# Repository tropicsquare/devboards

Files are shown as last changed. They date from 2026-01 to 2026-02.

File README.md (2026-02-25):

# TROPIC01 devboards
Welcome, PCB designers! 

This repository collects all resources for development boards which we designed with our TROPIC01 secure element. All PCB designs are freely available under **[CERN-OHL-P-2.0](https://ohwr.org/cernohl) Open Hardware license**. We encourage you to re-use designs, modify, or build your own boards!

> [!TIP]
> **Looking for code examples, ready to get started?** Head over to [libtropic](https://github.com/tropicsquare/libtropic) and pick a tutorial that matches your interests. Whether you're new to secure elements or building production systems, you'll find step-by-step guides to get you up and running quickly.

| Product name | HW resources | Description | Image  |
|:---:|:---:|:---:|:---:|
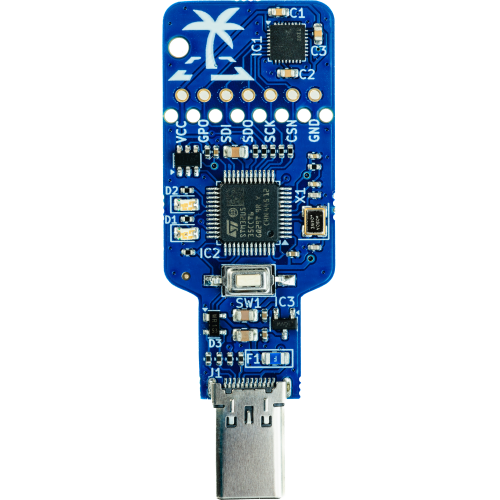
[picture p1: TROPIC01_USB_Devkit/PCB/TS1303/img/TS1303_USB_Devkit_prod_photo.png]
| **TROPIC01 USB Devkit** | [View](./TROPIC01_USB_Devkit/) | Suitable for TROPIC01 evaluation over USB. Besides the default functionality of SPI-UART translator which you can plug into PC and evaluate tropic on your laptop by using its serial port, this devkit is also capable of running USB application, because it contain also application MCU. This is ideal starting point for developing own USB application with TROPIC01. |  |
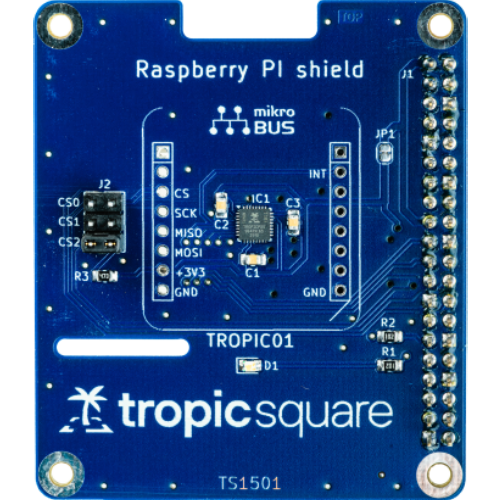
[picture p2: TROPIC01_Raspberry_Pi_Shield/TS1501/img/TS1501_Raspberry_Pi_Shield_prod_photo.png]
| **TROPIC01 Raspberry Pi Shield**  | [View](./TROPIC01_Raspberry_Pi_Shield/) | Chip is wired to SPI port pins commonly used on Raspberry Pi, ideally use this shield if you want to evaluate on `Raspberry Pi` or some other `Linux SBC` with the `Raspberry Pi` compatible header.  |  |
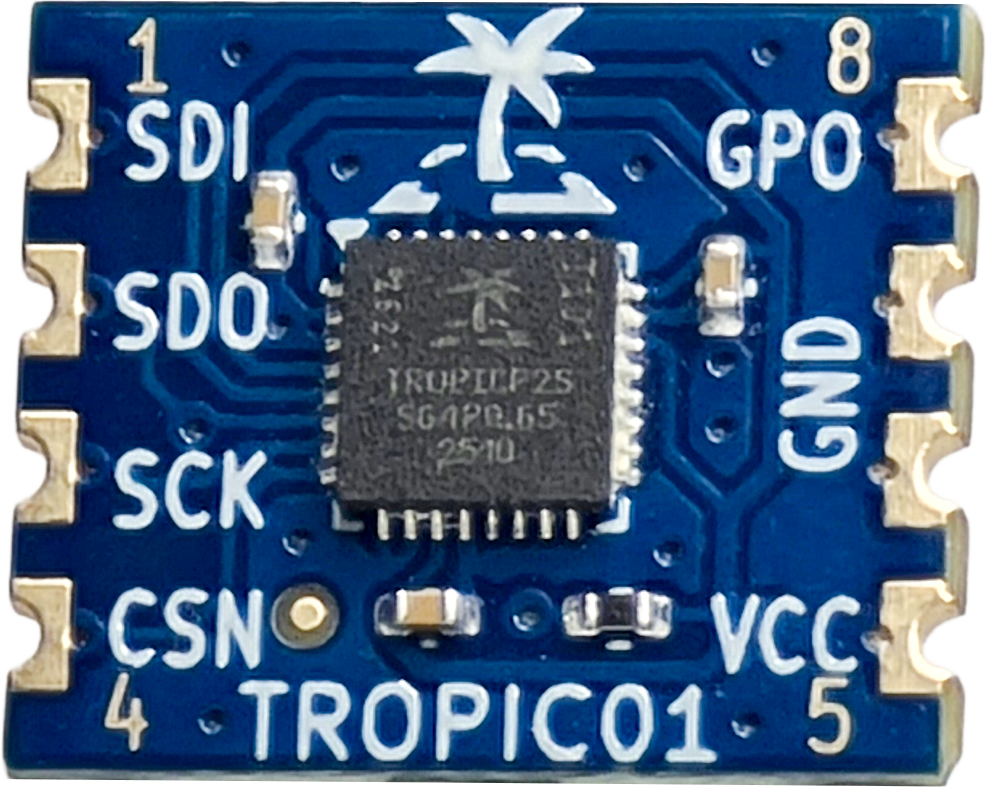
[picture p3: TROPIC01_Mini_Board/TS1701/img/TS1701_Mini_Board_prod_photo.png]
| **TROPIC01 Mini Board** | [View](./TROPIC01_Mini_Board/) | Minimalistic PCB breakout board for TROPIC01, designed to be soldered directly on host PCB, keeping the size small but still handy to hand solder. Suitable for placing on custom made shields or prototyping when PCB space is scarce. |  |
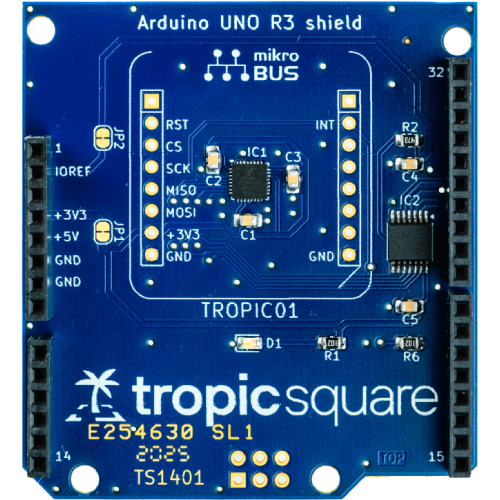
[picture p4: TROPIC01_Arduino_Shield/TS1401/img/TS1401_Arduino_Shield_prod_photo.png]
| **TROPIC01 Arduino Shield** | [View](./TROPIC01_Arduino_Shield/) | Chip is wired to SPI port pins commonly used on arduino compatible boards. Ideally use this shield if you want to evaluate on prototype which has `Arduino` header. |  |
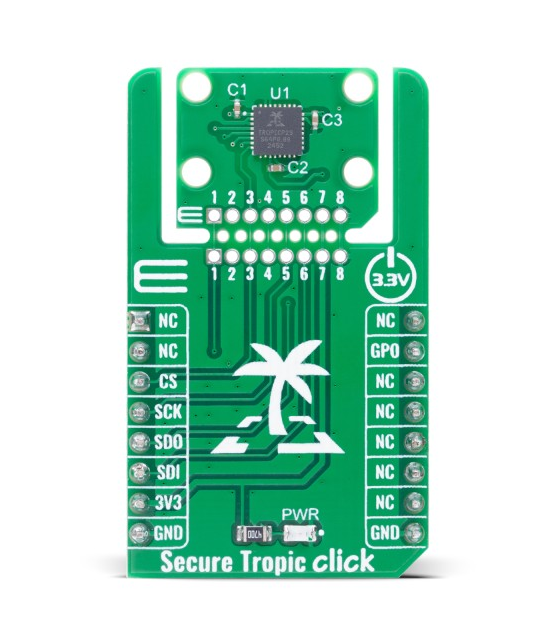
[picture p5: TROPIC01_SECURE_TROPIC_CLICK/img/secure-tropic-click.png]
| **TROPIC01 SECURE TROPIC CLICK**  | [View](./TROPIC01_SECURE_TROPIC_CLICK/) | Tthis is a third party devboard, with the similar functionality as other shields, but with another form factor. Fits into mikroBUS socket, or could be wired over wires as needed.|  |

## Using These Designs

Each particular board folder contains complete design files for all released revisions:
- **Schematics** (`.kicad_sch`) - Showing how components are wired together
- **PCB layouts** (`.kicad_pcb`) - Design of the PCB - how components are physically placed on the PCB
- **BOMs** - Component lists with part numbers
- **Gerbers** - Manufacturing files for PCB fabrication

You're free to use these as reference, modify for your needs, or manufacture your own boards.

> [!IMPORTANT]
> Some devboards include firmware in their folders. Note that firmware or its parts may be under various licensing schemes - see the [licensing section](#license) below for details.

## FAQ

See [FAQ.md](FAQ.md)

## Support & Warranty

These designs and devkits are provided as-is for evaluation and prototyping. No warranties are provided, and no production certifications (e.g., CE/FCC) are implied. Support is best-effort; for code examples and guidance, see [libtropic](https://github.com/tropicsquare/libtropic).

## License

This repository does not contain only PCB resources, but in some cases also HW which comes with devkit. Each part is under different license, more details in following table:

| Component | License  | Applies To |
|:---|:---|:---|
| **PCB Hardware** | [CERN-OHL-P-2.0](LICENSE.txt) | TROPIC01_Arduino_Shield/, TROPIC01_Raspberry_Pi_Shield/, TROPIC01_Mini_Board/, TROPIC01_USB_Devkit/PCB/ |
| **Firmware** | [BSD-3-Clause-Clear](LICENSES/FIRMWARE-LICENSE.txt) | TROPIC01_USB_Devkit/firmwares/ |
| **Third-party USB library** | Specific | TROPIC01_USB_Devkit/firmwares/firmware_B/sdk/ - See [LICENSES/NOTICE.txt](LICENSES/NOTICE.txt) |

## About TROPIC01

For more information about the TROPIC01 secure element, please see the official documentation:

*   [TROPIC01 Development resources](https://github.com/tropicsquare/tropic01/tree/main/)
*   [TROPIC01 Website](https://www.tropicsquare.com/tropic01)

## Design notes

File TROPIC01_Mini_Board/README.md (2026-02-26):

# TROPIC01 Mini Board

This repository contains **hardware** design files for the TROPIC01 Mini Board.

> [!TIP]
> **Looking for code examples, ready to get started?** Head over to [libtropic](https://github.com/tropicsquare/libtropic) and pick a tutorial that matches your interests. Whether you're new to secure elements or building production systems, you'll find step-by-step guides to get you up and running quickly.

## PCB Revisions + BOMs

Following folder contains schematics, layouts, BOMs and gerber files.

- **PCB [TS1701](./TS1701/)**

## Product Versions

| Product version | PCB Tracking | PCB Revision | TROPIC01 Part Number | BOM | Picture | Availability |
|:---:|:---:|:---:|:---:|:---:|:---:|:-----:|
| 2.0 | none | **TS1702** | TR01-C2P-T101 | [BOM](./TS1702/bom/ts17-tropic01-mini.csv) | [Top View](./TS1702/img/top.png) | [BUY HERE](https://www.tropicsquare.com/order-devkit)  |
| 1.0 | none | **TS1701** | TR01-C2P-T101 | [BOM](./TS1701/bom/ts17-tropic01-mini.csv) | [Top View](./TS1701/img/top.png) | [BUY HERE](https://www.tropicsquare.com/order-devkit)  |

## About TROPIC01

For more information about the TROPIC01 secure element, please see the official documentation:

*   [TROPIC01 Development resources](https://github.com/tropicsquare/tropic01/tree/main/)
*   [TROPIC01 Website](https://www.tropicsquare.com/tropic01)

## Support & Warranty

This board is provided as-is for evaluation and prototyping. No warranties are provided, and no production certifications (e.g., CE/FCC) are implied. Community-level support only; for examples and tutorials, visit [libtropic](https://github.com/tropicsquare/libtropic).

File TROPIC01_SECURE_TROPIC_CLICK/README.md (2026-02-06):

# TROPIC01 SECURE TROPIC CLICK

This repository contains references for TROPIC01 SECURE TROPIC CLICK. Please note that this Devboard is not developed by Tropic Square.

> [!TIP]
> **Looking for code examples, ready to get started?** Head over to [libtropic](https://github.com/tropicsquare/libtropic) and pick a tutorial that matches your interests. Whether you're new to secure elements or building production systems, you'll find step-by-step guides to get you up and running quickly.

## PCB Revisions + BOMs

None avaiable (Developed by MIKRO-E)

## Product Versions

| Product version | PCB Tracking | PCB Revision | TROPIC01 Part Number | BOM | Picture | Availability |
|:---:|:---:|:---:|:---:|:---:|:---:|:-----:|
| 1.1 | none | none | TR01-C2P-T101 | External vendor | [Top View](./img/secure-tropic-click.png) | [BUY HERE](https://www.tropicsquare.com/order-devkit)  |
| 1.0 | none | none | TR01-B2S-T005 | External vendor | [Top View](./img/secure-tropic-click.png) | [DEPRECATED]  |

## About TROPIC01

For more information about the TROPIC01 secure element, please see the official documentation:

*   [TROPIC01 Development resources](https://github.com/tropicsquare/tropic01/tree/main/)
*   [TROPIC01 Website](https://www.tropicsquare.com/tropic01)

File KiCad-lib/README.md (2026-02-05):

# TROPIC01 KiCad Library

This directory contains support files for designing PCB with TROPIC01, **Tested with KiCad 9.0**.

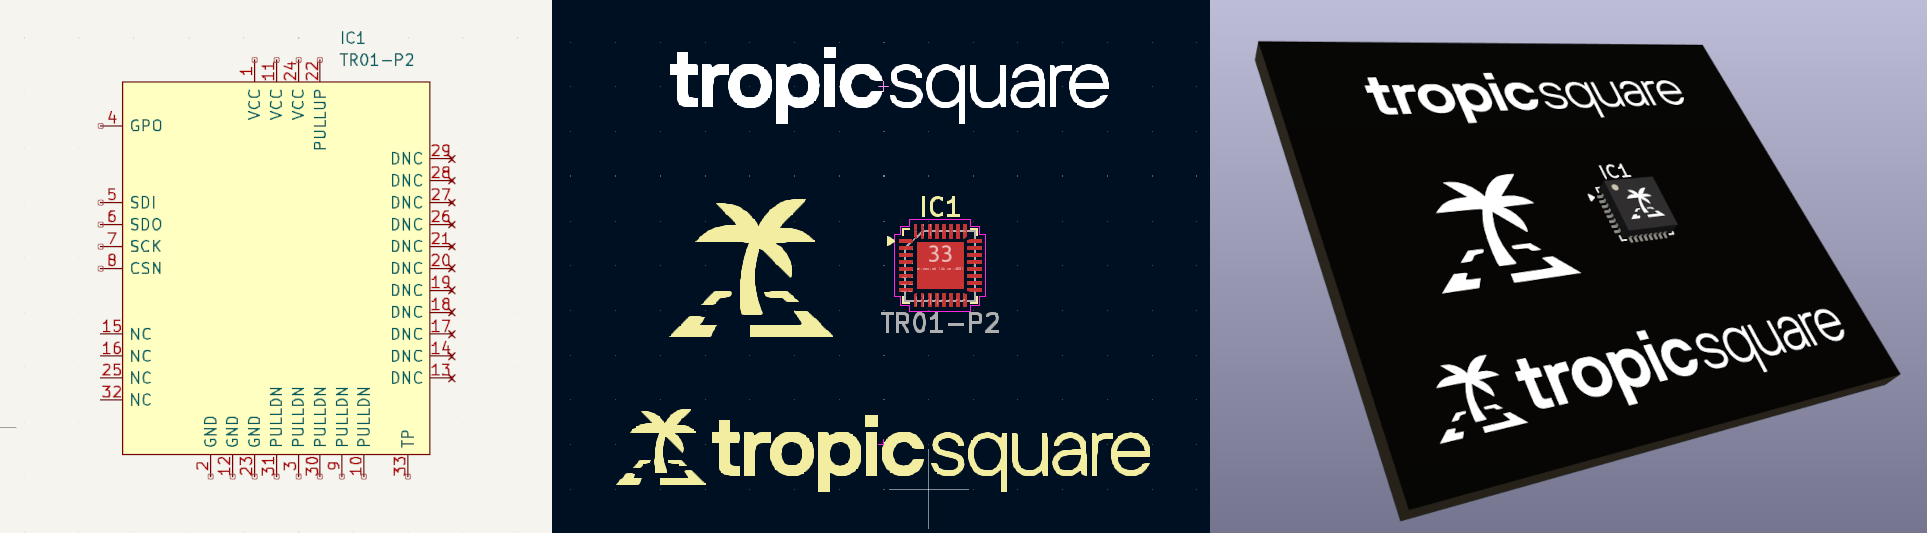
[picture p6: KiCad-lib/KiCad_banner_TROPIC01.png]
KiCad printscreens


## Content

- `TROPIC01.kicad_sym` - Symbol library containing schematic symbol for TROPIC01 chip
- `TROPIC01.step` - 3D STEP model for the TROPIC01 chip package
- `logos.pretty/` - Tropic Square logo and branding, provided as footprints, ready to be used in silkscreen

As footprint we recommend to use standard `Package_DFN_QFN:QFN-32-1EP_4x4mm_P0.4mm_EP2.65x2.65mm` provided by KiCad.

## Installation and Usage as Project-Specific Libraries (Recommended)

This method keeps the libraries just with your project. For more details refer to original KiCad documentation about how to use libraries.

1. **Copy the KiCad-lib folder** into your KiCad project directory or a subdirectory (e.g., `libraries/`)

2. **Add the Library:**
  - Open your KiCad project
  - Go to `Preferences` → `Manage Symbol Libraries...`
  - In the "Project Specific Libraries" tab, click the folder icon to add a new library
  - Browse to and select `TROPIC01.kicad_sym`
  - Give it a nickname (e.g., "TROPIC_SQUARE")
  - Click OK

3. **Add the Footprint Library:**
  - Go to `Preferences` → `Manage Footprint Libraries...`
  - In the "Project Specific Libraries" tab, click the folder icon to add a new library
  - Browse to and select the `logos.pretty` folder
  - Give it a nickname (e.g., "TROPIC_SQUARE"_Logos")
  - Click OK

4. **Configure 3D Model Path:**

By default, KiCad uses the standard 3D model for the QFN32 footprint. You can override this with our custom model to display the palm tree logo on the TROPIC01 package in the 3D viewer. To use our 3D model:
  - Open the PCB editor
  - Select a TROPIC01 footprint
  - Right-click → `Properties` → `3D Models` tab
  - Update the path so it points to provided `TROPIC01.step`

## Adding Logo Footprints to PCB

The logo footprints are designed for PCB silkscreen branding. They include various sizes to fit different board designs. These footprints contain only graphical elements and have no electrical connections.

1. Open the PCB Editor
2. Click the "Add Footprint" button (or press `O`)
3. In the footprint chooser, search for "tropicsquare"
4. Select the desired logo variant:
   - `tropicsquare_logo` - Full logo (default size)
   - `tropicsquare_logo_7` - Logo, 7mm
   - `tropicsquare_logo_8` - Logo, 8mm
   - `tropicsquare_name_7` - Company name text, 7mm
   - `tropicsquare_palm` - Palm icon (default size)
   - `tropicsquare_palm_8` - Palm icon, 8mm
   - `tropicsquare_palm_10` - Palm icon, 10mm
5. Place it on your PCB (typically on the silkscreen layer)

## License

See the LICENSE.txt file in the root directory for licensing information.

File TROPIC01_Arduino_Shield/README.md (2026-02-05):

# TROPIC01 Arduino Shield

This repository contains **hardware** design files for the TROPIC01 Arduino Shield.

> [!TIP]
> **Looking for code examples, ready to get started?** Head over to [libtropic](https://github.com/tropicsquare/libtropic) and pick a tutorial that matches your interests. Whether you're new to secure elements or building production systems, you'll find step-by-step guides to get you up and running quickly.

## PCB Revisions + BOMs

Following folder contains schematics, layouts, BOMs and gerber files.

- **PCB [TS1401](./TS1401/)**

## Product Versions

| Product version | PCB Tracking | PCB Revision | Product Variant | TROPIC01 Part Number  | BOM | Picture | Availability |
|:---:|:---:|:---:|:---:|:---:|:---:|:---:|:-----:|
| 1.2 | none | **TS1401** | Assembled with MikroBUS socket | TR01-C2P-T103 | [BOM](./TS1401/bom/bom_variant_microbus.csv) | [Top View](./TS1401/img/top.png) | [BUY HERE](https://www.tropicsquare.com/order-devkit) |
| 1.1 | E254630 SL1 |**TS1401**  | Assembled with chip | TR01-C2P-T101 | [BOM](./TS1401/bom/bom_variant_chip.csv) | [Top View](./TS1401/img/top.png) | [BUY HERE](https://www.tropicsquare.com/order-devkit) |
| 1.0 | E254630 SL1 | **TS1401** | Assembled with chip | TR01-B2S-T005 | [BOM](./TS1401/bom/bom_variant_chip.csv) | [Top View](./TS1401/img/top.png) | DEPRECATED  |

## About TROPIC01

For more information about the TROPIC01 secure element, please see the official documentation:

*   [TROPIC01 Development resources](https://github.com/tropicsquare/tropic01/tree/main/)
*   [TROPIC01 Website](https://www.tropicsquare.com/tropic01)

## Support & Warranty

This shield is provided as-is for evaluation and prototyping. No warranties are provided, and no production certifications (e.g., CE/FCC) are implied. Community-level support only; for examples and tutorials, visit [libtropic](https://github.com/tropicsquare/libtropic).

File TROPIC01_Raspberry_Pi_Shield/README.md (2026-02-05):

# TROPIC01 Raspberry Pi Shield

This repository contains **hardware** design files for the TROPIC01 Raspberry Pi Shield.

> [!TIP]
> **Looking for code examples, ready to get started?** Head over to [libtropic](https://github.com/tropicsquare/libtropic) and pick a tutorial that matches your interests. Whether you're new to secure elements or building production systems, you'll find step-by-step guides to get you up and running quickly.

## PCB Revisions + BOMs

Following folder contains schematics, layouts, BOMs and gerber files.

- **PCB [TS1501](./TS1501/)**

## Product Versions

| Product version | PCB Tracking | PCB Revision | TROPIC01 Part Number | BOM | Picture | Availability |
|:---:|:---:|:---:|:---:|:---:|:---:|:-----:|
| 1.2 | none | **TS1501** | TR01-C2P-T103  | [BOM](./TS1501/bom/bom_variant_chip.csv) | [Top View](./TS1501/img/top.png) | [BUY HERE](https://www.tropicsquare.com/order-devkit)  |
| 1.1 | none | **TS1501** | TR01-C2P-T101  | [BOM](./TS1501/bom/bom_variant_chip.csv) | [Top View](./TS1501/img/top.png) | DEPRECATED  |
| 1.0 | none | **TS1501** | TR01-B2S-T005  | [BOM](./TS1501/bom/bom_variant_chip.csv) | [Top View](./TS1501/img/top.png) | DEPRECATED  |

## About TROPIC01

For more information about the TROPIC01 secure element, please see the official documentation:

*   [TROPIC01 Development resources](https://github.com/tropicsquare/tropic01/tree/main/)
*   [TROPIC01 Website](https://www.tropicsquare.com/tropic01)

## Support & Warranty

This shield is provided as-is for evaluation and prototyping. No warranties are provided, and no production certifications (e.g., CE/FCC) are implied. Community-level support only; for examples and tutorials, visit [libtropic](https://github.com/tropicsquare/libtropic).

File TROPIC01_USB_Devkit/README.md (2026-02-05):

# TROPIC01 USB Devkit

This repository contains **hardware** design files for the TROPIC01 USB Devkit.

> [!TIP]
> **Looking for code examples, ready to get started?** Head over to [libtropic](https://github.com/tropicsquare/libtropic) and pick a tutorial that matches your interests. Whether you're new to secure elements or building production systems, you'll find step-by-step guides to get you up and running quickly.

## PCB Revisions + BOMs

Following folders contain schematics, layouts, BOMs and gerber files.

- **PCB [TS1301](./PCB/TS1301/)**
- **PCB [TS1302](./PCB/TS1302/)**
- **PCB [TS1303](./PCB/TS1303/)**

## Product Versions

| Product version | PCB Tracking  | PCB Revision  | MCU | TROPIC01 Part Number | BOM | Firmware | Picture | Availability |
|:----:|:---:|:---:|:---:|:---:|:---:|:---:|:---:|:-----:|
| 3.1  | none | **TS1303** | STM32U5 (512kB) | TR01-C2P-T103 | [BOM](./PCB/TS1303/bom/bom.csv) | [FW B](./firmwares/firmware_B/) | [Top View](./PCB/TS1303/img/top.png)  | [BUY HERE](https://www.tropicsquare.com/order-devkit)  |
| 3.0  | none | **TS1303** | STM32U5 (512kB) | TR01-C2P-T202 | [BOM](./PCB/TS1303/bom/bom.csv) | [FW B](./firmwares/firmware_B/) | [Top View](./PCB/TS1303/img/top.png)  | DEPRECATED  |
| 2.0  | none | **TS1302** | STM32U5 (256kB) | TR01-C2P-T101 | [BOM](./PCB/TS1302/bom/bom.csv) | [FW B](./firmwares/firmware_B/) | [Top View](./PCB/TS1302/img/top.png)  | DEPRECATED  |
| 1.0  | none | **TS1301** | STM32F1 (256kB) | TR01-B2S-T005 | [BOM](./PCB/TS1301/bom/bom.csv) | [FW A](./firmwares/firmware_A/) | [Top View](./PCB/TS1301/img/top.png)  | DEPRECATED  |
## PCB Specifications

Common specifications for all revisions:
- **Layers**: 2-layer
- **Thickness**: 1.0 mm
- **Material**: FR4
- **Solder Mask**: Blue
- **Silkscreen**: Yes (top and bottom)

### Assembly Notes

Standard SMD components (0805 size):
- Resistor tolerance: 5% (unless specified)
- Capacitor tolerance: 20% (unless specified)

## About TROPIC01

For more information about the TROPIC01 secure element, please see the official documentation:

*   [TROPIC01 Development resources](https://github.com/tropicsquare/tropic01/tree/main/)
*   [TROPIC01 Website](https://www.tropicsquare.com/tropic01)

## Support & Warranty

This devkit is provided as-is for evaluation and prototyping. No warranties are provided, and no production certifications (e.g., CE/FCC) are implied. Community-level support only; for examples and tutorials, visit [libtropic](https://github.com/tropicsquare/libtropic).

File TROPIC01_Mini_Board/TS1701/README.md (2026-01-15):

# TROPIC01 mini

This repository contains design files for the TROPIC01 minimal integration board TS17xx.
The ultimately small board for any purpose. Just control pins with power pins and that’s it. 

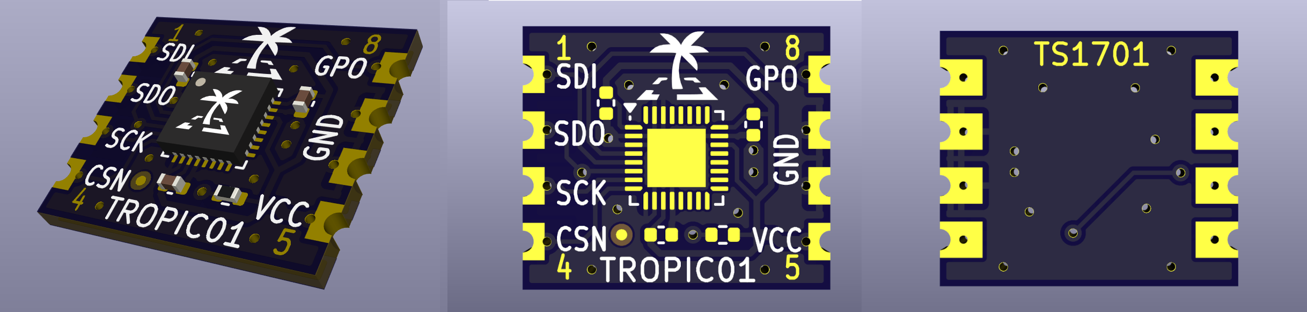
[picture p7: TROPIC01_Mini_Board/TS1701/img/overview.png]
PCB view


## Project structure

* `*.kicad_pro` - KiCad project file
* `*.kicad_sch` - Schematic file
* `*.kicad_pcb` - PCB layout file
* `./gerber/` - Generated gerber data for PCB manufacturing
* `./bom/` - Bill of materials including order codes, interactive BOM and assembly coordinates
* `./img/` - Images (PCB renders)
* `*_schematics.pdf` - Exported schematic diagrams (latest version)

# Manufacturing instructions

## PCB

 - Number of cu layers: 2
 - Board Thickness: 1.0
 - Core: FR4
 - Size: 14 x 12 mm
 - Mask: Blue
 - Silkscreen: Yes (TOP)
 - Castellated holes

## Assembly

There are no any special requirements for C and R components.
Where not specified the R tolerance is 5% and C 20%.

# About TROPIC01

For more information about the TROPIC01 secure element, please see the official documentation:

*   [TROPIC01 Datasheet](https://github.com/tropicsquare/tropic01/tree/main/doc/datasheet)
*   [TROPIC01 Website](https://www.tropicsquare.com/tropic01)

## Getting Started

To interact with the TROPIC01 chip on Linux-based systems like Raspberry Pi OS and Ubuntu, we provide the 
[`libtropic-linux`](https://github.com/tropicsquare/libtropic-linux) repository, containing integration examples 
of our platform-independent SDK, [`libtropic`](https://github.com/tropicsquare/libtropic).

 > [!IMPORTANT]
 > Before you start with various examples, we strongly recommend to do two things first:
 > * Read CHIP ID and TROPIC01's firmware versions and **save printed output for future reference**
 > * Update TROPIC01's both internal firmware to latest version.

In [`libtropic-linux`](https://github.com/tropicsquare/libtropic-linux) repository, you can find specific instruction for both operations based on hardware you use.

### Command line utility

Once you saved results of `show_chip_id_and_fw_ver` example (for future reference) and after your chip is updated with `fw_update` example, 
you can test our command line application. Check out [`libtropic-util`](https://github.com/tropicsquare/libtropic-util) repository, 
you can find there specific instruction based on hardware you use.

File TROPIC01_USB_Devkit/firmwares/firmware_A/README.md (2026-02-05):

# About

USB to SPI master converter FW for PCB TS01xx.

USB-CDC class (`/dev/ttyACM*`).

# STM32 based firmware

Minimal requirements:

 * linux compatible os
 * arm-none-eabi-gcc

Tools installation i.e.:

```
apt install gcc-arm-none-eabi
```

Flashing tools install:

```
apt install stlink-tools
```

# Project structure

Current setup for CPU STM32F103xB.

```
├── app                 # application main directory
│   └── build           # application build directory
├── doc                 # device documentation
├── hw                  # hardware definitions
└── sdk                 # submodule (sdk-stm32)
    ├── common          # universal libraries
    ├── doc             # stm32 documentation
    ├── drv_f1          # stm32f1xx drivers
    ├── hal             # HW abstraction layer (universal)
    └── stm32
        ├── CMSIS
        │   ├── device  # MCU definitions 
        │   ├── inc     # stm32 core definitions
        │   ├── linker  # linker files
        │   └── src     # stm32 core sources
        └── STM32F1xx_HAL_Driver # submodule (STMicroelectronics)
```

Project uses nested git submodules. Use `git submodule update --init --recursive`.

## Application

Build:

```
$ cd ./app
$ make
$ make flash
```

# Function

Create USB character device /dev/ttyACMx. 

USB identification (see `./usb/usbd_desc.c`):
```
USBD_VID                 =  1155 == 0x0483 == "STMicroelectronics"
USBD_PID_FS              = 22336 == 0x5740 == "Virtual COM Port"
USBD_MANUFACTURER_STRING = "TropicSquare"
USBD_PRODUCT_STRING_FS   = "SPI interface"
```

Communication uses ASCII characters lines ended by `\r` or `\n` (0x0D or 0x0A).

To send SPI data just put HEX values string (i.e. "0A1B2C3D") and new line character. 
Any such line will issue CS low signal and line end will issue CS high signal.
Character `x` or `\` at the end of line will cause leaving CS low (continuous data reading).

Received data will be printed the same way (same number bytes as send).

## Commands

* `HELP` : Print quick help
* `AUTO=<mode>[,<get_resp>,<no_resp>]` : Automatic response reading set \
    `<mode>` : 1 = enable, 0 = disable (default 0)
    `<get_resp>` : HEX value of byte used for reading
    `<no_resp>` : HEX value of byte which mean no response available
* `CLKDIV` : Show SCK clock divisor current value.
* `CLKDIV=<n>` : SCK clock divisor set \
    `<n>` : 2,4,8,16,32,64,128 or 256 to select SCK frequency as `72MHz / <n>`
* `CS` : Show SPI CS state (1 == active == LOW) 
* `CS=<n>` : Set SPI CS state (0 == idle, 1 == active == LOW) 
* `GPO` : Show GPO state 
* `ID` : Request product id
* `MODE` : Show MODE state (`TEST_MODE`,`SCAN_MODE`,`FTEST_MODE`,`SEL_EXT_CLK`) \
      Command supported only on TS01 HW
* `PWR` : Show power status.
* `PWR=<mode>` : Get/set target power \
    `<mode>` : 1 = power ON, 0 = power OFF
* `RESET` : Instant reset
* `SN`: Request product serial number, same as `iSerial` identification on USB.
* `VER` : Request version information

Execution of any command is finished with message "OK" or "ERROR" (see below).

## Error results

In case of some error, response "`ERROR: <reason>`" will be send.

Possible error results `<reason>`:

* "illegal parameter"
* "invalid parameter"
* "missing parameter"
* "unknown command"
* "USB RX overflow !"

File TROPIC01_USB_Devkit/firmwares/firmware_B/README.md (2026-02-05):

# About

This is a minimalistic USB firmware used by TROPIC01's [USB devkit](https://github.com/tropicsquare/tropic01-stm32u5-usb-devkit-hw). It is based on the **STM32U535** microcontroller and its primary function is to act as a USB-to-SPI master converter (master then talks to TROPIC01's slave SPI interface).

> [!WARNING]
> This firmware only facilitates raw data transfer between the TROPIC01 and a host-side application.
> Key handling and security must be managed by the host application.

> [!TIP]
> Although this firmware is minimalistic by design, the **STM32U535** MCU offers significantly more capabilities (e.g., secure key storage).
> Users are encouraged to develop custom firmware to leverage these features for enhanced functionality.

# Usage

For basic low-level test open **any serial port application**, then follow instruction described in [`API.md`](./API.md).

> [!TIP]
> To release the full potential of TROPIC01, we recommend to explore and evaluate examples using [libtropic-linux](https://github.com/tropicsquare/libtropic-linux) repository.
> For bash users we provide also command line application [libtropic-util](https://github.com/tropicsquare/libtropic-util).

# Updating devkit's firmware

For compilation you need to have:

 * Linux compatible OS
 * `arm-none-eabi-gcc` (could be installed with `apt install gcc-arm-none-eabi`) 
 * `dfu-util` (could be installed with `apt install dfu-util`)

> [!IMPORTANT]
> Do not forget to update submodules with `git submodule update --init --recursive`

## Build firmware

Once tools are installed, build firmware with following commands:
```
$ cd ./app
$ make clean
$ make
```

## Flash firmware

1) Build FW (see chapter [Build firmware](#build-firmware))
2) Press button and (while pressed) connect to USB, then release.
   Devkit will be connected as USB device "STMicroelectronics STM Device in DFU Mode"
3) run following command `dfu-util`:
   ```bash
   dfu-util -a 0 -s 0x08000000:leave -D build/app.bin
   ```
4) after successful update the device starts FW automatically

# Project structure

Description of all folders:

```
├── app                 # application main directory
│   └── build           # application build directory
├── doc                 # device documentation
├── hw                  # hardware definitions
├── usb                 # usb interface to usb library
└── sdk                 # sdk root (stm32), may be submodule
    ├── common          # universal libraries
    ├── drv_*           # stm32 drivers
    ├── hal             # HW abstraction layer (universal)
    └── stm32
        ├── CMSIS
        │   ├── device  # MCU definitions
        │   ├── inc     # stm32 core definitions
        │   ├── linker  # linker files
        │   └── src     # stm32 core sources
        ├── STM32_USBX_Library   # MS Azure USBX library provided by STM
        └── STM32U5xx_HAL_Driver # submodule (STMicroelectronics)
```

Project uses nested git submodules. Use `git submodule update --init --recursive`.

# Manufacturing notes

USB identification (see `./usb/ux_device_descriptors.h`):
```
USBD_VID                 =  1155 == 0x0483 == "STMicroelectronics"
USBD_PID_FS              = 22336 == 0x5740 == "Virtual COM Port"
USBD_MANUFACTURER_STRING = "TropicSquare"
USBD_PRODUCT_STRING_FS   = "SPI interface"
```

For manufacturing purposes there is `flash_tool.sh` script, which does
automatic flashing and communication testing.

It requires some tools installed :
```
apt install coreutils usbutils dfu-util
```

Prior to use, you have to build the FW and then simply execute the script and follow instructions.

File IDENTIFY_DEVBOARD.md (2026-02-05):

# How to Identify Your TROPIC01 Development Board

Each Dev Board has a identification present on PCB in silkscreen or exposed copper as a text.

## PCB marking meaning:
   - **PCB Revision** - Defines the PCB revision.
      - **TS1701** - Mini Board PCB revision 1
      - **TS1303** - USB Devkit PCB revision 3
   - **PCB Tracing** - Links PCB revision with a bom and production.
      - **none** - Some PCBs do not have any additional Tracking data present. :(
      - **E254630 SL1** - Tracking present on Arduino Shield PCB.

Some early devboards were distributed without proper marking and may contain TROPIC01 engineering samples.

## Identification Process

1. **Check PCB marking** on the board's text (top/bottom, edges, or corners)
 
2. **Compare with tables** in each devboard folder:
   - [TROPIC01_USB_Devkit/README.md](./TROPIC01_USB_Devkit/README.md)
   - [TROPIC01_Arduino_Shield/README.md](./TROPIC01_Arduino_Shield/README.md)
   - [TROPIC01_Raspberry_Pi_Shield/README.md](./TROPIC01_Raspberry_Pi_Shield/README.md)
   - [TROPIC01_Mini_Board/README.md](./TROPIC01_Mini_Board/README.md)
3. **If you still cannot identify your board**, you probably have one of early engineering devices
   - Use "identify chip" tutorial in [libtropic](https://github.com/tropicsquare/libtropic)
   - The TROPIC01 part number will appear in the debug output

## Troubleshooting

**No marking found?** Check the board's physical shape and form factor, then use the libtropic tutorial to identify the chip.

**Custom or pre-production board?** Contact Tropic Square support with a photo of your board.

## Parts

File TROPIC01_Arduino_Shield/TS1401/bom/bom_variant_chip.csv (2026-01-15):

Reference | Value | Footprint | Qty | DNP | OC_MOUSER
C1,C2,C3,C4,C5 | 100n | Capacitor_SMD:C_0805_2012Metric_Pad1.18x1.45mm_HandSolder | 5 |  | 187-CL21B104KBFNNNE
CON1 | TROPIC01 | ts_mikrobus:TROPIC01_mikrobus | 1 |  | dont assembly
D1 | LED_G | LED_SMD:LED_0805_2012Metric | 1 |  | 710-150080GS75000
IC1 | TROPIC01_chip | tropic01_chip:QFN-32-1EP_4x4mm_P0.4mm_EP2.65x2.65mm | 1 |  | TR01-C2P-T103
IC2 | TXU0304PWR | Package_SO:TSSOP-14_4.4x5mm_P0.65mm | 1 |  | 595-TXU0304PWR
R1,R6 | 1k | Resistor_SMD:R_0805_2012Metric_Pad1.20x1.40mm_HandSolder | 2 |  | 603-RC0805JR-071KL
R2 | 47k | Resistor_SMD:R_0805_2012Metric_Pad1.20x1.40mm_HandSolder | 1 |  | 603-RC0805JR-0747KL
Shield1 | Arduino_Uno_R3_Shield | shields:Arduino_Uno_R3_Shield | 1 |  | 474-PRT-11417 (set of 4 connectors)

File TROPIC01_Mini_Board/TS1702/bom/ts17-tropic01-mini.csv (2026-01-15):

Reference | Qty | Value | DNP | Exclude from BOM | Exclude from Board | Footprint | Datasheet | OC_MOUSER
C1,C2,C3 | 3 | 100n |  |  |  | Capacitor_SMD:C_0402_1005Metric | ~ | 80-C0402C104M4RAUTO
IC1 | 1 | TROPIC01_chip |  |  |  | tropic01_chip:QFN-32-1EP_4x4mm_P0.4mm_EP2.65x2.65mm |  | T101
R1 | 1 | 47k |  |  |  | Resistor_SMD:R_0402_1005Metric | ~ | 652-CR0402JW-473GLF

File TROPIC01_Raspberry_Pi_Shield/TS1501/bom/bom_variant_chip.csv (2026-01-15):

Reference | Value | Footprint | Qty | DNP | OC_MOUSER
C1,C2,C3 | 100n | Capacitor_SMD:C_0805_2012Metric_Pad1.18x1.45mm_HandSolder | 3 |  | 187-CL21B104KBFNNNE
CON1 | TROPIC01 | ts_mikrobus:TROPIC01_mikrobus | 1 | DNP | dont assemble
D1 | LED_G | LED_SMD:LED_0805_2012Metric | 1 |  | 710-150080GS75000
IC1 | TROPIC01_chip | tropic01_chip:QFN-32-1EP_4x4mm_P0.4mm_EP2.65x2.65mm | 1 |  | TR01-C2P-T103
J1 | RPI socket | shields:RPI_Hat_B+ | 1 |  | 474-PRT-16764
J2 | CS select jumper switch | Connector_PinHeader_2.54mm:PinHeader_2x03_P2.54mm_Vertical | 1 |  | 653-XG8T-0641 + 653-XJ8A-0211
R1,R2 | 1k | Resistor_SMD:R_0805_2012Metric_Pad1.20x1.40mm_HandSolder | 2 |  | 603-RC0805JR-071KL
R3 | 47k | Resistor_SMD:R_0805_2012Metric_Pad1.20x1.40mm_HandSolder | 1 |  | 603-RC0805JR-0747KL

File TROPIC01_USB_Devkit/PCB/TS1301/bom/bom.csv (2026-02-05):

Reference | Value | Footprint | Qty | DNP | OC_MOUSER
C1,C2,C3 | 100n/603 | Capacitor_SMD:C_0603_1608Metric | 3 |  | 80-C0603104K3RAC7411
C4,C7 | 4u7/16V | Capacitor_SMD:C_0805_2012Metric | 2 |  | 187-CL21A475KAQNNNE
C5,C6,C9,C13,C14 | 100n | Capacitor_SMD:C_0805_2012Metric | 5 |  | 187-CL21B104KBFNNNE
C8,C10 | 10n | Capacitor_SMD:C_0805_2012Metric | 2 |  | 187-CL21B103KCANNNC
C11,C12 | 10p | Capacitor_SMD:C_0805_2012Metric | 2 |  | 187-CL21C100CBANNNC
D1 | LED_R | LED_SMD:LED_0805_2012Metric | 1 |  | 710-150080RS75000
D2 | PRTR5V0U2X | Package_TO_SOT_SMD:SOT-143 | 1 |  | 771-PRTR5V0U2X-T/R
F1 | Fuse 500mA | Resistor_SMD:R_0805_2012Metric_Pad1.20x1.40mm_HandSolder | 1 |  | 594-MFU0805FF00500P1
IC1 | TROPIC01_chip | tropic01_chip:QFN-32-1EP_4x4mm_P0.4mm_EP2.65x2.65mm | 1
IC2 | AZ1117C-33 | Package_TO_SOT_SMD:SOT-223 | 1 |  | 621-AZ1117CH-3.3TRG1
IC3 | STM32F103C8Tx | Package_QFP:LQFP-48_7x7mm_P0.5mm | 1 |  | 511-STM32F103C8T6
IC4 | TPS22917DBV | Package_TO_SOT_SMD:SOT-23-6 | 1 |  | 595-TPS22917DBVR
J1 | USB_C_Plug | _con_misc:USB_C_plug_USB4155_03_C | 1 |  | 640-USB4155-03C
R1 | 33k | Resistor_SMD:R_0805_2012Metric | 1 |  | 603-RC0805FR-1333KL
R2,R3,R4,R5,R6,R11 | 1k | Resistor_SMD:R_0805_2012Metric | 6 |  | 603-RC0805JR-071KL
R7 | 1k5 | Resistor_SMD:R_0805_2012Metric | 1 |  | 279-CRGCQ0805F10R
R8,R9 | 10R | Resistor_SMD:R_0805_2012Metric | 2 |  | 279-CRGCQ0805F10R
R10 | 220R | Resistor_SMD:R_0805_2012Metric | 1 |  | 603-RC0805JR-07220RL
R12,R13 | 5k1 | Resistor_SMD:R_0805_2012Metric | 2 |  | 652-CR0805FX-5101ELF
X1 | 8MHz | Crystal:Crystal_SMD_0603-4Pin_6.0x3.5mm | 1 |  | 774-406C35D08M00000

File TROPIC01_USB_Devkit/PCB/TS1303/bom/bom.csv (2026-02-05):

Reference | Value | Footprint | Qty | DNP | OC_MOUSER
C1,C2,C3 | 100n/603 | Capacitor_SMD:C_0603_1608Metric | 3 |  | 80-C0603104K3RAC7411
C4,C7,C14 | 4u7/16V | Capacitor_SMD:C_0805_2012Metric | 3 |  | 187-CL21A475KAQNNNE
C5,C6,C9,C13 | 100n | Capacitor_SMD:C_0402_1005Metric | 4 |  | 80-C0402C104M4RECTU
C8,C10 | 10n | Capacitor_SMD:C_0402_1005Metric | 2 |  | 80-C0402C103M4R
C11,C12 | 10p | Capacitor_SMD:C_0402_1005Metric | 2 |  | 80-C0402C100J5G
D1 | LED_R | LED_SMD:LED_0805_2012Metric | 1 |  | 710-150080RS75000
D2 | LED_G | LED_SMD:LED_0805_2012Metric | 1 |  | 710-150080GS75000
D3 | PRTR5V0U2X | Package_TO_SOT_SMD:SOT-143 | 1 |  | 771-PRTR5V0U2X-T/R
F1 | Fuse 500mA | Resistor_SMD:R_0805_2012Metric_Pad1.20x1.40mm_HandSolder | 1 |  | 594-MFU0805FF00500P1
IC1 | TROPIC01_chip | tropic01_chip:QFN-32-1EP_4x4mm_P0.4mm_EP2.65x2.65mm | 1
IC2 | STM32U535CCTx | Package_QFP:LQFP-48_7x7mm_P0.5mm | 1 |  | 511-STM32U535CCT6
IC3 | TPS7A0533PDBZR | Package_TO_SOT_SMD:SOT-23-3 | 1 |  | 595-TPS7A0533PDBZR
IC4 | TPS22917DBV | Package_TO_SOT_SMD:SOT-23-6 | 1 |  | 595-TPS22917DBVR
J1 | USB_C_Plug | _con_misc:USB_C_plug_UP20CFGFL-P12 | 1 |  | 179-UP20CFGFLP12TR
R1 | 33k | Resistor_SMD:R_0402_1005Metric | 1 |  | 603-RC0402DR-0733KL
R2,R3,R4,R5,R6,R7,R13,R14 | 1k | Resistor_SMD:R_0402_1005Metric | 8 |  | 603-RE0402DRE071KL
R8 | 5k1 | Resistor_SMD:R_0402_1005Metric | 1 |  | 791-RGC1/16SC5101DTH
R9,R10 | 10R | Resistor_SMD:R_0402_1005Metric | 2 |  | 603-RC0402DR-0710RL
R11 | 1k5 | Resistor_SMD:R_0402_1005Metric | 1 |  | 603-RE0402DRE071K5L
R12 | 220R | Resistor_SMD:R_0402_1005Metric | 1 |  | 652-CR0402JW-221GLF
SW1 | tact switch | _mechanical:button_PTS636_M25SMTR | 1 |  | 611-PTS636SM25SMTRLF
X1 | 8MHz | Crystal:Crystal_SMD_3225-4Pin_3.2x2.5mm | 1 |  | 729-FL0800008Q

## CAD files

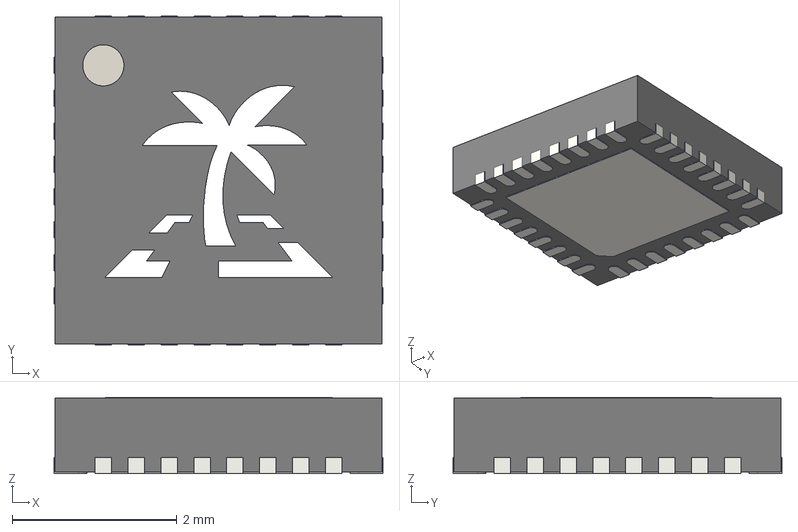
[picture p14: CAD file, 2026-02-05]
KiCad-lib/TROPIC01.step
4.00 x 4.00 x 0.93 mm
QFN-32-1EP_4x4mm_Pitch0.4mm
Sketch001

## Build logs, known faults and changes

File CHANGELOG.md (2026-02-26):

# Changelog

All additions of hardware designs in this repository are documented here.

## [2026-02-26]
- Added 1702 - New HW revision for Mini Board, which fits into 2.54mm spacing.

### Initial commit

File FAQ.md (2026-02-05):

# Frequently Asked Questions (FAQ)

**Quick Links:**
- [I got a devboard, now what?](#i-got-a-devboard-now-what)
- [My devboard does not contain version markings](#my-devboard-does-not-contain-version-markings)
- [I want to design PCB](#i-want-to-design-pcb)

---

## I got a devboard, now what?

We recommend to follow tutorial in [libtropic](https://github.com/tropicsquare/libtropic)!

## My devboard does not contain version markings

You probably have one of very early produced devboards. Please follow instruction [here](IDENTIFY_DEVBOARD.md).

## I want to design PCB

TROPIC01 `Schematic symbol`, `3D model` and `Tropic Square logos` for silkscreen are available in `KiCad-lib/` folder, ready to be used with **KiCad** EDA tool. Check out [README.md](KiCad-lib/README.md) for details.

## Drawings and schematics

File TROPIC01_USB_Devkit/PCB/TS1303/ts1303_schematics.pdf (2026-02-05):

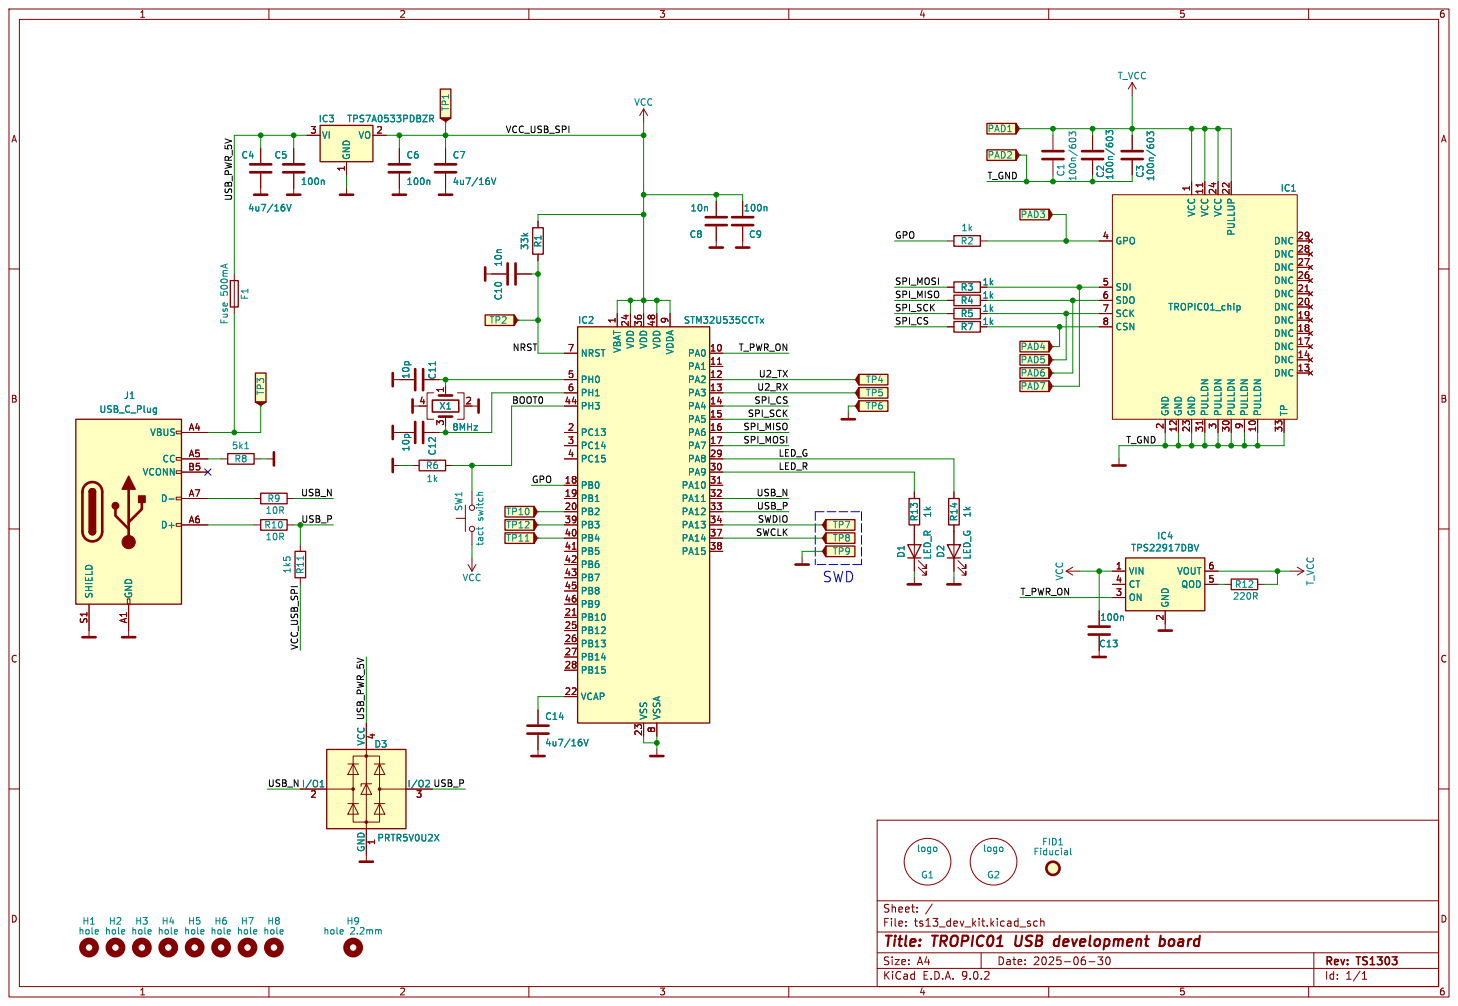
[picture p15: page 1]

1 GND 23 VCC 11 PULLDN 31 VCC 24 PULLDN

9 PULLDN 10 TP 33 DNC 29 DNC 28 DNC 27 DNC 26 DNC 21 DNC 20 DNC 19 DNC 18 DNC 17 DNC 14 DNC 13 R13 1k C13

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

1 VDD 24 VDD 36 VSS 23 VDD 48 VSSA

Id: 1/1 Title: TROPIC01 USB development board

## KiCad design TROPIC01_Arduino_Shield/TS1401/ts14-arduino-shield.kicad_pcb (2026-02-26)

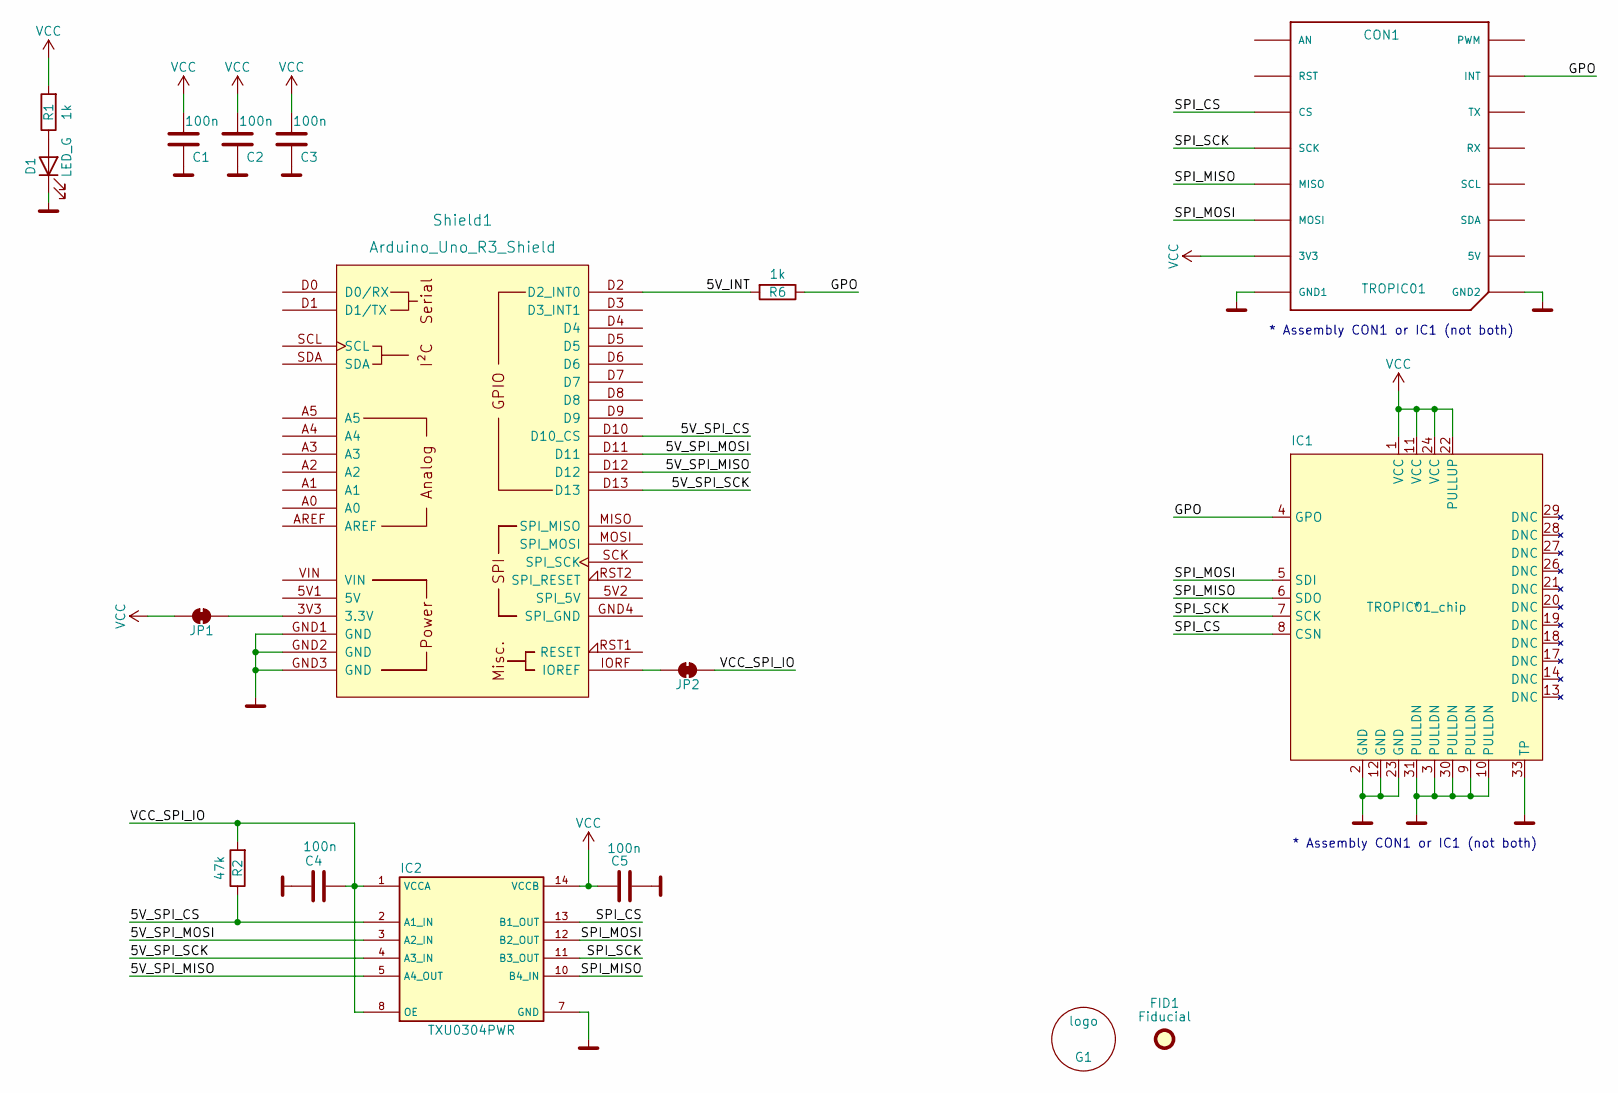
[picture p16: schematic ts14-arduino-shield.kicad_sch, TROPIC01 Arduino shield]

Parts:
C1, C2, C3, C4, C5: 100n; C_0805_2012Metric_Pad1.18x1.45mm_HandSolder
CON1: TROPIC01; TROPIC01_mikrobus
D1: LED_G; LED_0805_2012Metric
FID1: Fiducial; Fiducial_0.5mm_Mask1mm
G1: logo; tropicsquare_logo
IC1: TROPIC01_chip; QFN-32-1EP_4x4mm_P0.4mm_EP2.65x2.65mm
IC2: TXU0304PWR; TSSOP-14_4.4x5mm_P0.65mm
JP1, JP2: SolderJumper_2_Bridged; SolderJumper-2_P1.3mm_Bridged
R1, R6: 1k; R_0805_2012Metric_Pad1.20x1.40mm_HandSolder
R2: 47k; R_0805_2012Metric_Pad1.20x1.40mm_HandSolder
Shield1: Arduino_Uno_R3_Shield

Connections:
/5V_INT: R6.2, Shield1.D2 (D2_INT0)
/5V_SPI_CS: IC2.2 (A1_IN), R2.1, Shield1.D10 (D10_CS)
/5V_SPI_MISO: IC2.5 (A4_OUT), Shield1.D12
/5V_SPI_MOSI: IC2.3 (A2_IN), Shield1.D11
/5V_SPI_SCK: IC2.4 (A3_IN), Shield1.D13
/GPO: CON1.P15 (INT), IC1.4 (GPO), R6.1
/SPI_CS: CON1.P3 (CS), IC1.8 (CSN), IC2.13 (B1_OUT)
/SPI_MISO: CON1.P5 (MISO), IC1.6 (SDO), IC2.10 (B4_IN)
/SPI_MOSI: CON1.P6 (MOSI), IC1.5 (SDI), IC2.12 (B2_OUT)
/SPI_SCK: CON1.P4 (SCK), IC1.7 (SCK), IC2.11 (B3_OUT)
/VCC_SPI_IO: C4.1, IC2.1 (VCCA), IC2.8 (OE), JP2.1 (A), R2.2
GND: C1.1, C2.1, C3.1, C4.2, C5.1, CON1.P8 (GND1), CON1.P9 (GND2), D1.1 (K), IC1.2 (GND), IC1.3 (PULLDN), IC1.9 (PULLDN), IC1.10 (PULLDN), IC1.12 (GND), IC1.23 (GND), IC1.30 (PULLDN), IC1.31 (PULLDN), IC1.33 (TP), IC2.7 (GND), Shield1.GND1 (GND), Shield1.GND2 (GND), Shield1.GND3 (GND)
unnamed: D1.2 (A), R1.1
unnamed: JP1.1 (A), Shield1.3V3 (3.3V)
unnamed: JP2.2 (B), Shield1.IORF (IOREF)
VCC: C1.2, C2.2, C3.2, C5.2, CON1.P7 (3V3), IC1.1 (VCC), IC1.11 (VCC), IC1.22 (PULLUP), IC1.24 (VCC), IC2.14 (VCCB), JP1.2 (B), R1.2

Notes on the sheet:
* Assembly CON1 or IC1 (not both)

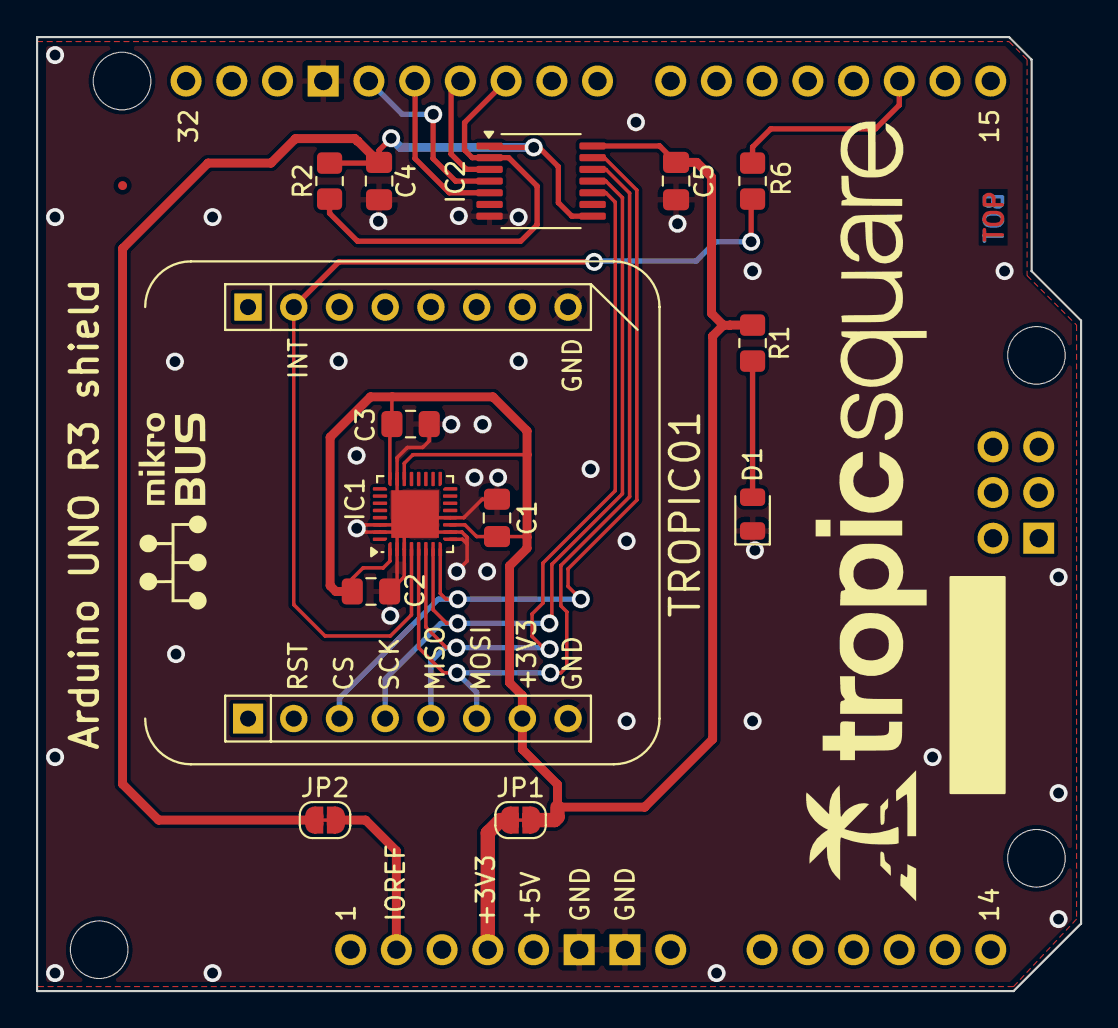
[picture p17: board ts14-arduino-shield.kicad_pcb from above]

Board: 2 copper layers, 58.0 x 53.0 mm, 17 parts (0 on the bottom side), 16 nets.

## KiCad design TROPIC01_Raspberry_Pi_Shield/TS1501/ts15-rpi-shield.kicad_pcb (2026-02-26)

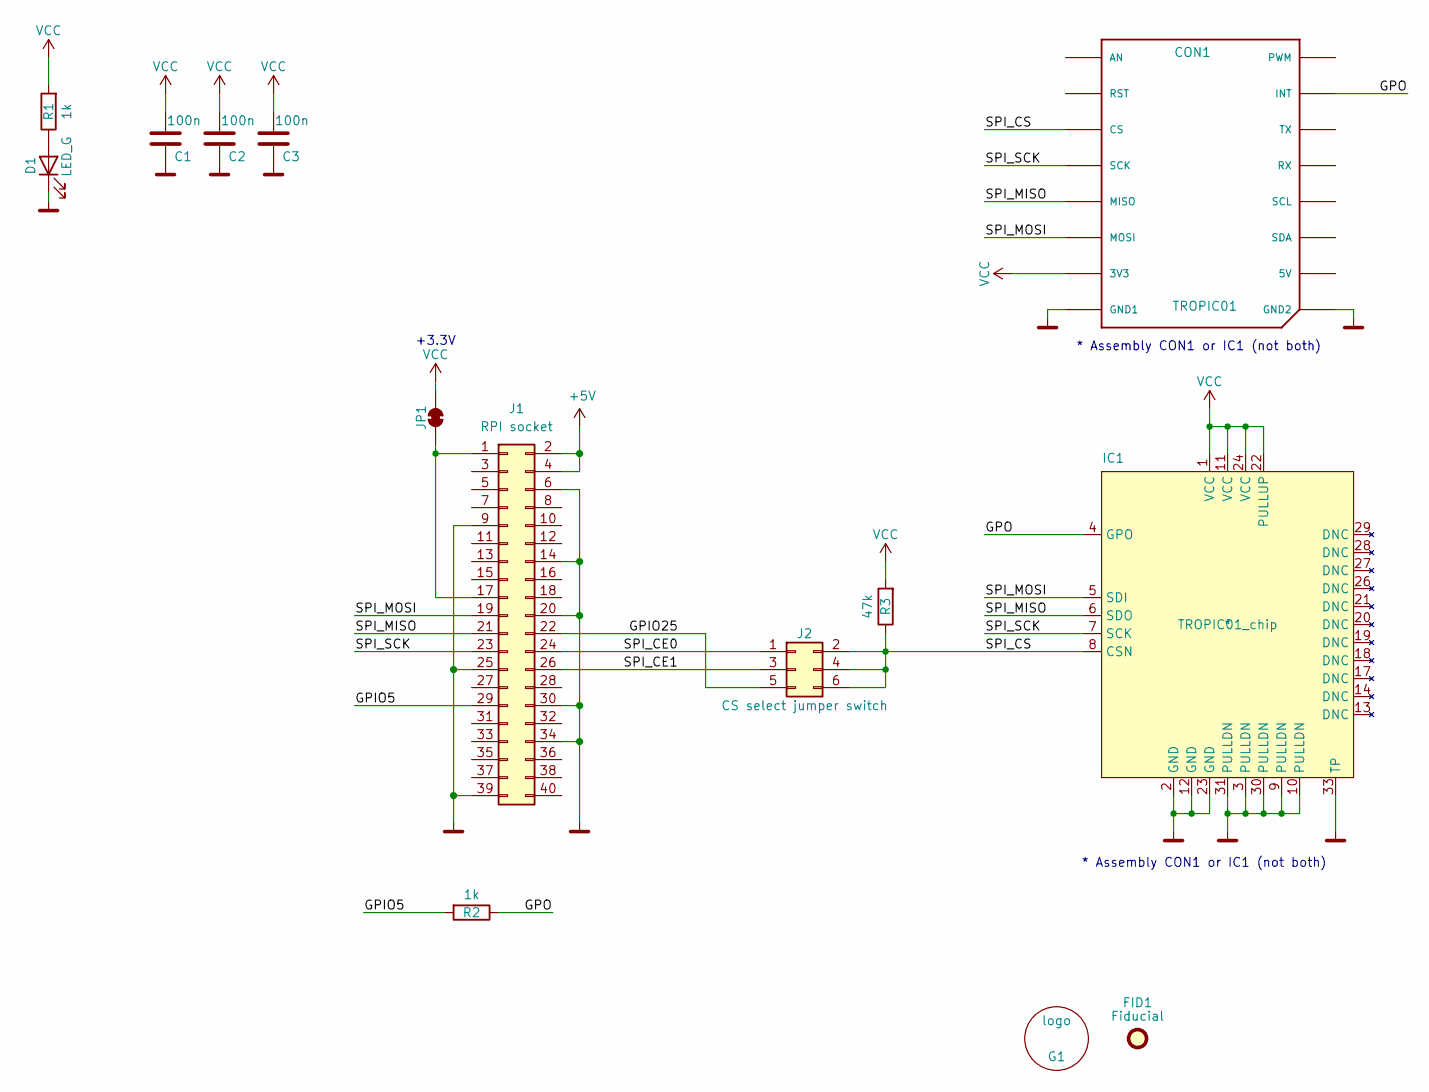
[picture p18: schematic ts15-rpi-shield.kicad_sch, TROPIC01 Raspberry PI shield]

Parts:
C1, C2, C3: 100n; C_0805_2012Metric_Pad1.18x1.45mm_HandSolder
CON1: TROPIC01; TROPIC01_mikrobus
D1: LED_G; LED_0805_2012Metric
FID1: Fiducial; Fiducial_0.5mm_Mask1mm
G1: logo; tropicsquare_logo
IC1: TROPIC01_chip; QFN-32-1EP_4x4mm_P0.4mm_EP2.65x2.65mm
J1: RPI socket; RPI_Hat_B+
J2: CS select jumper switch; PinHeader_2x03_P2.54mm_Vertical
JP1: SolderJumper_2_Bridged; SolderJumper-2_P1.3mm_Bridged
R1, R2: 1k; R_0805_2012Metric_Pad1.20x1.40mm_HandSolder
R3: 47k; R_0805_2012Metric_Pad1.20x1.40mm_HandSolder

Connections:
+5V: J1.2, J1.4
/GPIO5: J1.29, R2.2
/GPIO25: J1.22, J2.5
/GPO: CON1.P15 (INT), IC1.4 (GPO), R2.1
/SPI_CE0: J1.24, J2.1
/SPI_CE1: J1.26, J2.3
/SPI_CS: CON1.P3 (CS), IC1.8 (CSN), J2.2, J2.4, J2.6, R3.1
/SPI_MISO: CON1.P5 (MISO), IC1.6 (SDO), J1.21
/SPI_MOSI: CON1.P6 (MOSI), IC1.5 (SDI), J1.19
/SPI_SCK: CON1.P4 (SCK), IC1.7 (SCK), J1.23
GND: C1.1, C2.1, C3.1, CON1.P8 (GND1), CON1.P9 (GND2), D1.1 (K), IC1.2 (GND), IC1.3 (PULLDN), IC1.9 (PULLDN), IC1.10 (PULLDN), IC1.12 (GND), IC1.23 (GND), IC1.30 (PULLDN), IC1.31 (PULLDN), IC1.33 (TP), J1.6, J1.9, J1.14, J1.20, J1.25, J1.30, J1.34, J1.39
unnamed: D1.2 (A), R1.1
unnamed: J1.1, J1.17, JP1.1 (A)
VCC: C1.2, C2.2, C3.2, CON1.P7 (3V3), IC1.1 (VCC), IC1.11 (VCC), IC1.22 (PULLUP), IC1.24 (VCC), JP1.2 (B), R1.2, R3.2

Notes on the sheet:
+3.3V
* Assembly CON1 or IC1 (not both)

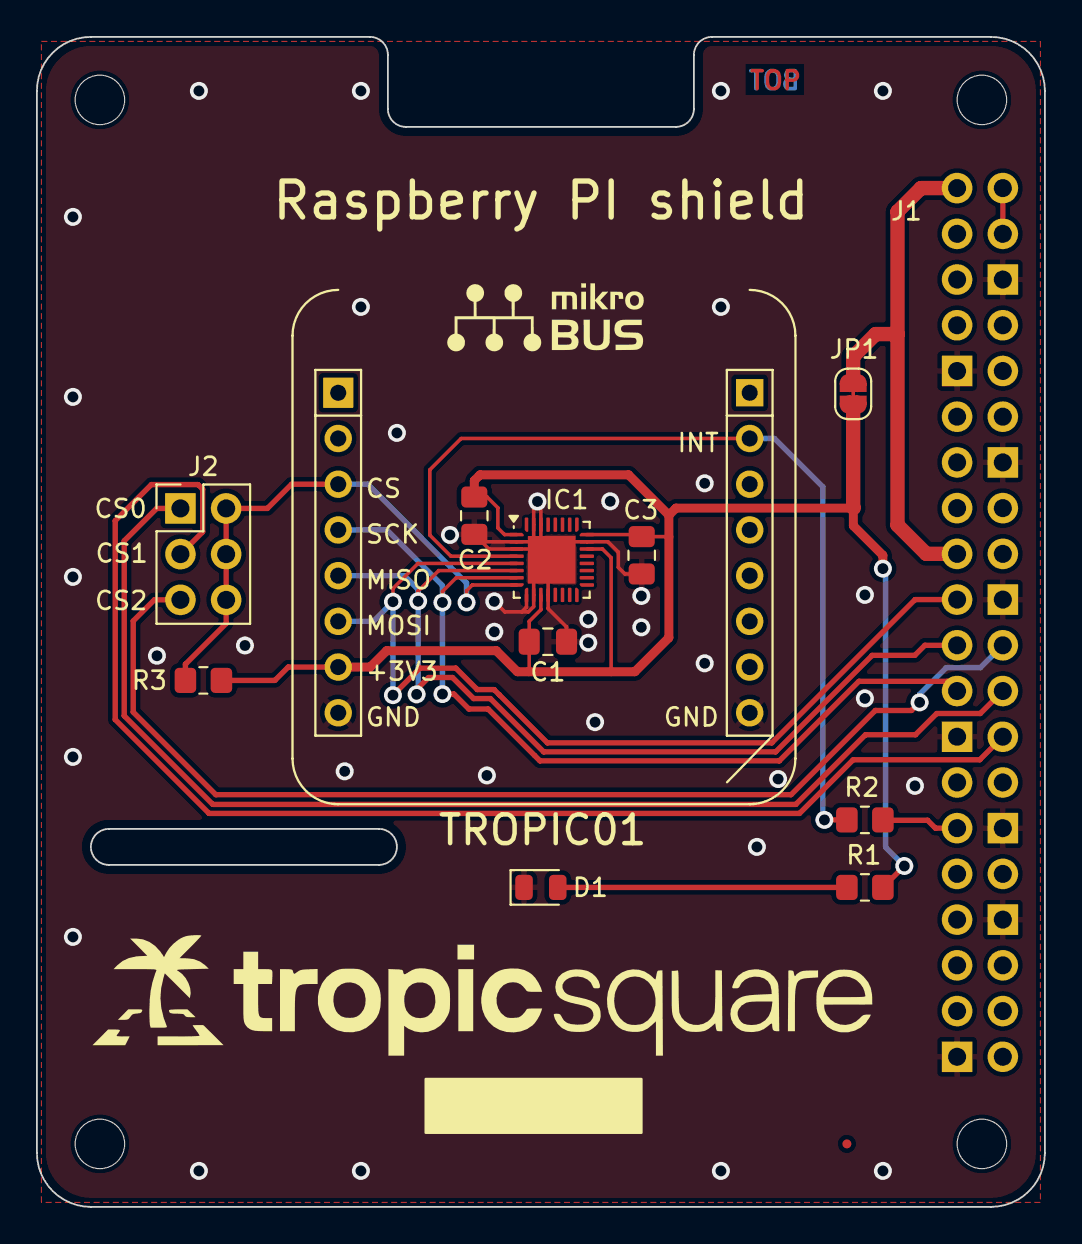
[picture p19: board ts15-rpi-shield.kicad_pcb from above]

Board: 2 copper layers, 56.0 x 65.0 mm, 14 parts (0 on the bottom side), 14 nets.

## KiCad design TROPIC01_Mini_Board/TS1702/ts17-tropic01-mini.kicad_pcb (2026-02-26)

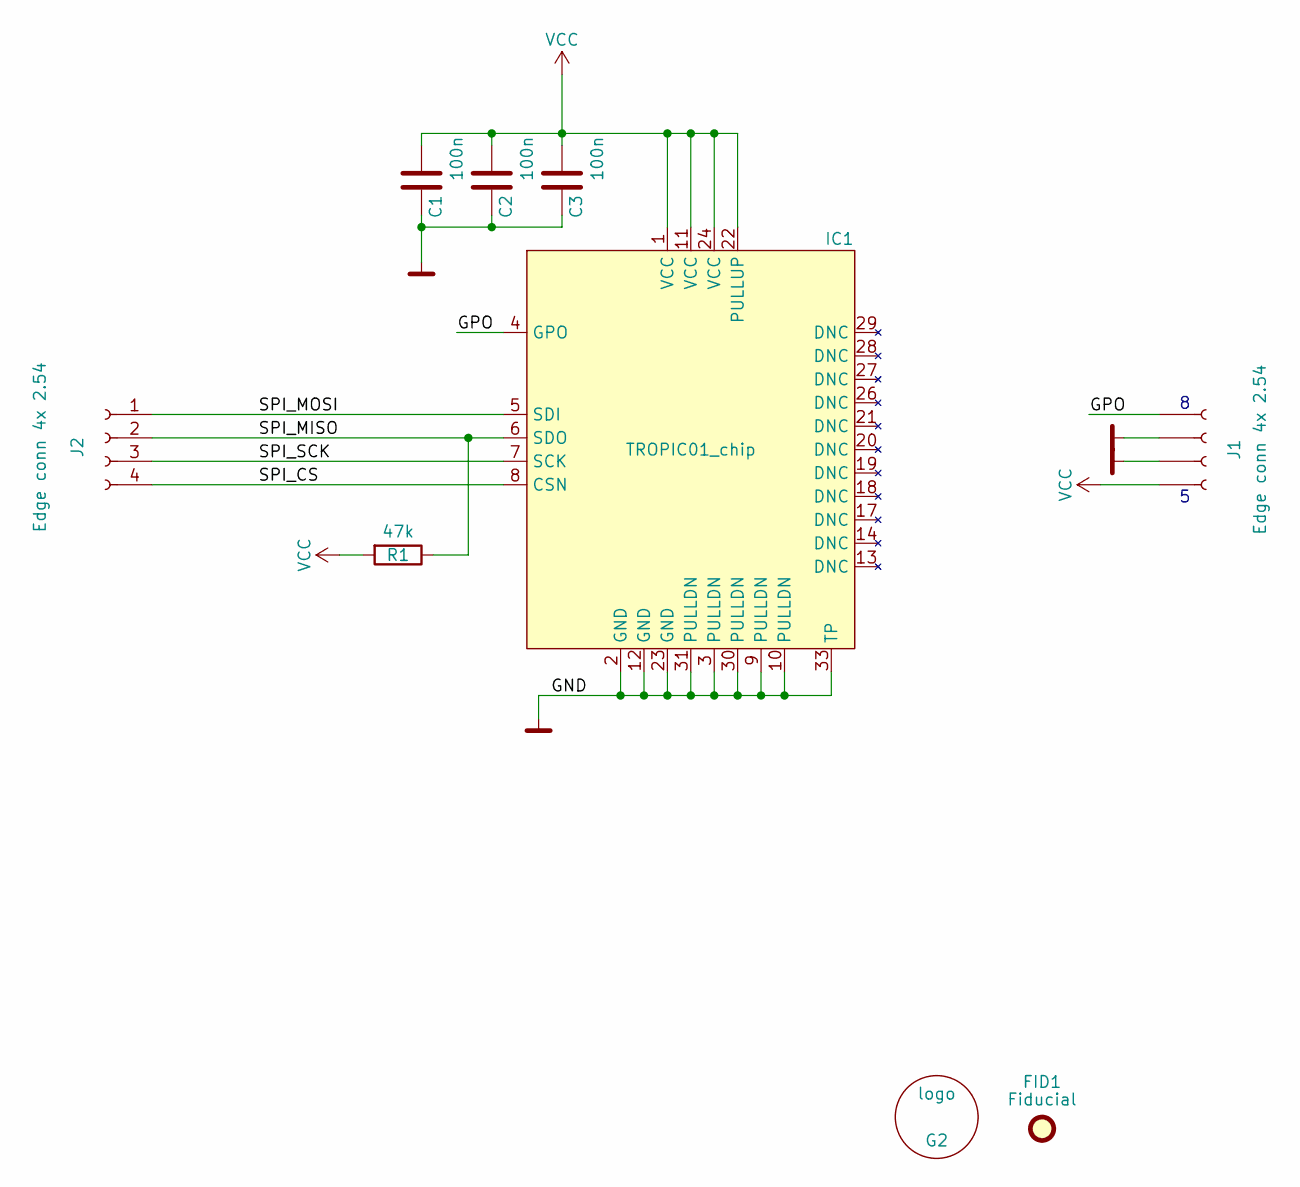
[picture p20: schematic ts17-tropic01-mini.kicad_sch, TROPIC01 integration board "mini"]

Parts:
C1, C2, C3: 100n; C_0402_1005Metric
FID1: Fiducial; Fiducial_0.5mm_Mask1mm
G2: logo; tropicsquare_palm_3
IC1: TROPIC01_chip; QFN-32-1EP_4x4mm_P0.4mm_EP2.65x2.65mm
J1, J2: Edge conn 4x 2.54; castellated_4x2.54
R1: 47k; R_0402_1005Metric

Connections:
/GPO: IC1.4 (GPO), J1.4
/SPI_CS: IC1.8 (CSN), J2.4
/SPI_MISO: IC1.6 (SDO), J2.2, R1.1
/SPI_MOSI: IC1.5 (SDI), J2.1
/SPI_SCK: IC1.7 (SCK), J2.3
GND: C1.1, C2.1, C3.1, IC1.2 (GND), IC1.3 (PULLDN), IC1.9 (PULLDN), IC1.10 (PULLDN), IC1.12 (GND), IC1.23 (GND), IC1.30 (PULLDN), IC1.31 (PULLDN), IC1.33 (TP), J1.2, J1.3
VCC: C1.2, C2.2, C3.2, IC1.1 (VCC), IC1.11 (VCC), IC1.22 (PULLUP), IC1.24 (VCC), J1.1, R1.2

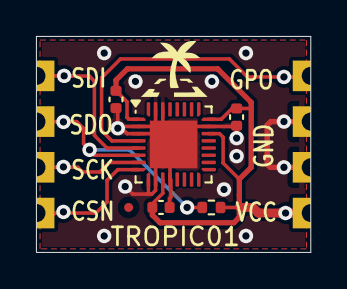
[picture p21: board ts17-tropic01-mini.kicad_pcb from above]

Board: 2 copper layers, 15.2 x 12.0 mm, 9 parts (0 on the bottom side), 7 nets.

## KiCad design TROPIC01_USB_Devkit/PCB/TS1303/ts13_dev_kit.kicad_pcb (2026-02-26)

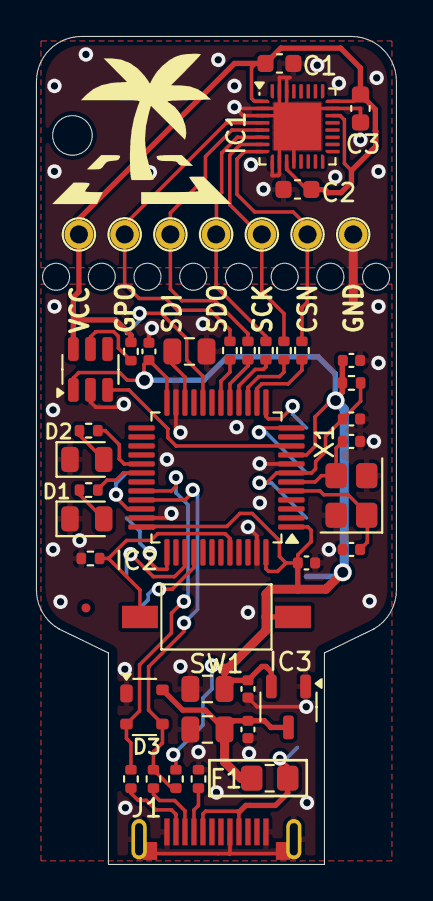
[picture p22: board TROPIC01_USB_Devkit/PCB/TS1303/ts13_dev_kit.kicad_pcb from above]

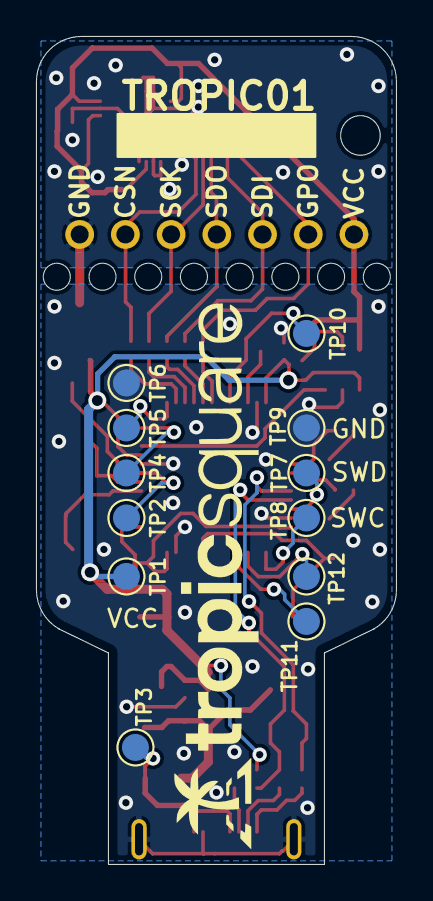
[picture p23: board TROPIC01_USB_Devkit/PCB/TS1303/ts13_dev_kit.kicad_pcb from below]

Board: 2 copper layers, 20.0 x 46.0 mm, 70 parts (13 on the bottom side), 38 nets.

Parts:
C1, C2, C3: 100n/603; C_0603_1608Metric
C4, C7, C14: 4u7/16V; C_0805_2012Metric
C5, C6, C9, C13: 100n; C_0402_1005Metric
C8, C10: 10n; C_0402_1005Metric
C11, C12: 10p; C_0402_1005Metric
D1: LED_R; LED_0805_2012Metric
D2: LED_G; LED_0805_2012Metric
D3: PRTR5V0U2X; SOT-143
F1: Fuse 500mA; R_0805_2012Metric_Pad1.20x1.40mm_HandSolder
FID1: Fiducial; Fiducial_0.5mm_Mask1mm
G1: logo; tropicsquare_palm_10
G2: logo; tropicsquare_logo_7
H1, H2, H3, H4, H5, H6, H7, H8: hole; Hole_1.5mm
H9: hole 2.2mm; Hole_2.2mm
IC1: TROPIC01_chip; QFN-32-1EP_4x4mm_P0.4mm_EP2.65x2.65mm
IC2: STM32U535CCTx; LQFP-48_7x7mm_P0.5mm
IC3: TPS7A0533PDBZR; SOT-23-3
IC4: TPS22917DBV; SOT-23-6
J1: USB_C_Plug; USB_C_plug_UP20CFGFL-P12
PAD1, PAD2, PAD3, PAD4, PAD5, PAD6, PAD7: TP; pad_1mm
R1: 33k; R_0402_1005Metric
R2, R3, R4, R5, R6, R7, R13, R14: 1k; R_0402_1005Metric
R8: 5k1; R_0402_1005Metric
R9, R10: 10R; R_0402_1005Metric
R11: 1k5; R_0402_1005Metric
R12: 220R; R_0402_1005Metric
SW1: tact switch; button_PTS636_M25SMTR
TP1, TP2, TP3, TP4, TP5, TP6, TP7, TP8, TP9, TP10, TP11, TP12: TP; TestPoint_1.5mm_noth
X1: 8MHz; Crystal_SMD_3225-4Pin_3.2x2.5mm

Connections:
/BOOT0: IC2.44 (PH3), R6.1, SW1.2
/GPO: IC2.18 (PB0), R2.2
/LED_G: IC2.29 (PA8), R14.2
/LED_R: IC2.30 (PA9), R13.2
/NRST: C10.1, IC2.7 (NRST), R1.2, TP2.1
/SPI_CS: IC2.14 (PA4), R7.2
/SPI_MISO: IC2.16 (PA6), R4.2
/SPI_MOSI: IC2.17 (PA7), R3.2
/SPI_SCK: IC2.15 (PA5), R5.2
/SWCLK: IC2.37 (PA14), TP8.1
/SWDIO: IC2.34 (PA13), TP7.1
/T_PWR_ON: IC2.10 (PA0), IC4.3 (ON)
/U2_RX: IC2.13 (PA3), TP5.1
/U2_TX: IC2.12 (PA2), TP4.1
/USB_N: D3.2 (I/O1), IC2.32 (PA11), R9.2
/USB_P: D3.3 (I/O2), IC2.33 (PA12), R10.2, R11.2
/USB_PWR_5V: C4.1, C5.1, D3.4 (VCC), F1.1, IC3.3 (VI)
GND: C1.1, C2.1, C3.1, C4.2, C5.2, C6.2, C7.2, C8.1, C9.1, C10.2, C11.2, C12.2, C13.1, C14.2, D1.1 (K), D2.1 (K), D3.1 (GND), IC1.2 (GND), IC1.3 (PULLDN), IC1.9 (PULLDN), IC1.10 (PULLDN), IC1.12 (GND), IC1.23 (GND), IC1.30 (PULLDN), IC1.31 (PULLDN), IC1.33 (TP), IC2.8 (VSSA), IC2.23 (VSS), IC2.35 (VSS), IC2.47 (VSS), IC3.1 (GND), IC4.2 (GND), J1.A1 (GND), J1.A12 (GND), J1.B12 (GND), J1.S1 (SHIELD), PAD2.1, R6.2, R8.2, TP6.1, TP9.1, X1.2, X1.4
unnamed: D1.2 (A), R13.1
unnamed: D2.2 (A), R14.1
unnamed: F1.2, J1.A4 (VBUS), J1.B9 (VBUS), TP3.1
unnamed: IC1.8 (CSN), PAD4.1, R7.1
unnamed: IC1.4 (GPO), PAD3.1, R2.1
unnamed: IC1.7 (SCK), PAD5.1, R5.1
unnamed: IC1.5 (SDI), PAD7.1, R3.1
unnamed: IC1.6 (SDO), PAD6.1, R4.1
unnamed: IC2.20 (PB2), TP10.1
unnamed: IC2.39 (PB3), TP12.1
unnamed: IC2.40 (PB4), TP11.1
unnamed: C11.1, IC2.5 (PH0), X1.1
unnamed: C12.1, IC2.6 (PH1), X1.3
unnamed: C14.1, IC2.22 (VCAP)
unnamed: IC4.5 (QOD), R12.1
unnamed: J1.A5 (CC), R8.1
unnamed: J1.A6 (D+), R10.1
unnamed: J1.A7 (D-), R9.1
T_VCC: C1.2, C2.2, C3.2, IC1.1 (VCC), IC1.11 (VCC), IC1.22 (PULLUP), IC1.24 (VCC), IC4.6 (VOUT), PAD1.1, R12.2
VCC: C6.1, C7.1, C8.2, C9.2, C13.2, IC2.1 (VBAT), IC2.9 (VDDA), IC2.24 (VDD), IC2.36 (VDD), IC2.48 (VDD), IC3.2 (VO), IC4.1 (VIN), R1.1, R11.1, SW1.1, TP1.1

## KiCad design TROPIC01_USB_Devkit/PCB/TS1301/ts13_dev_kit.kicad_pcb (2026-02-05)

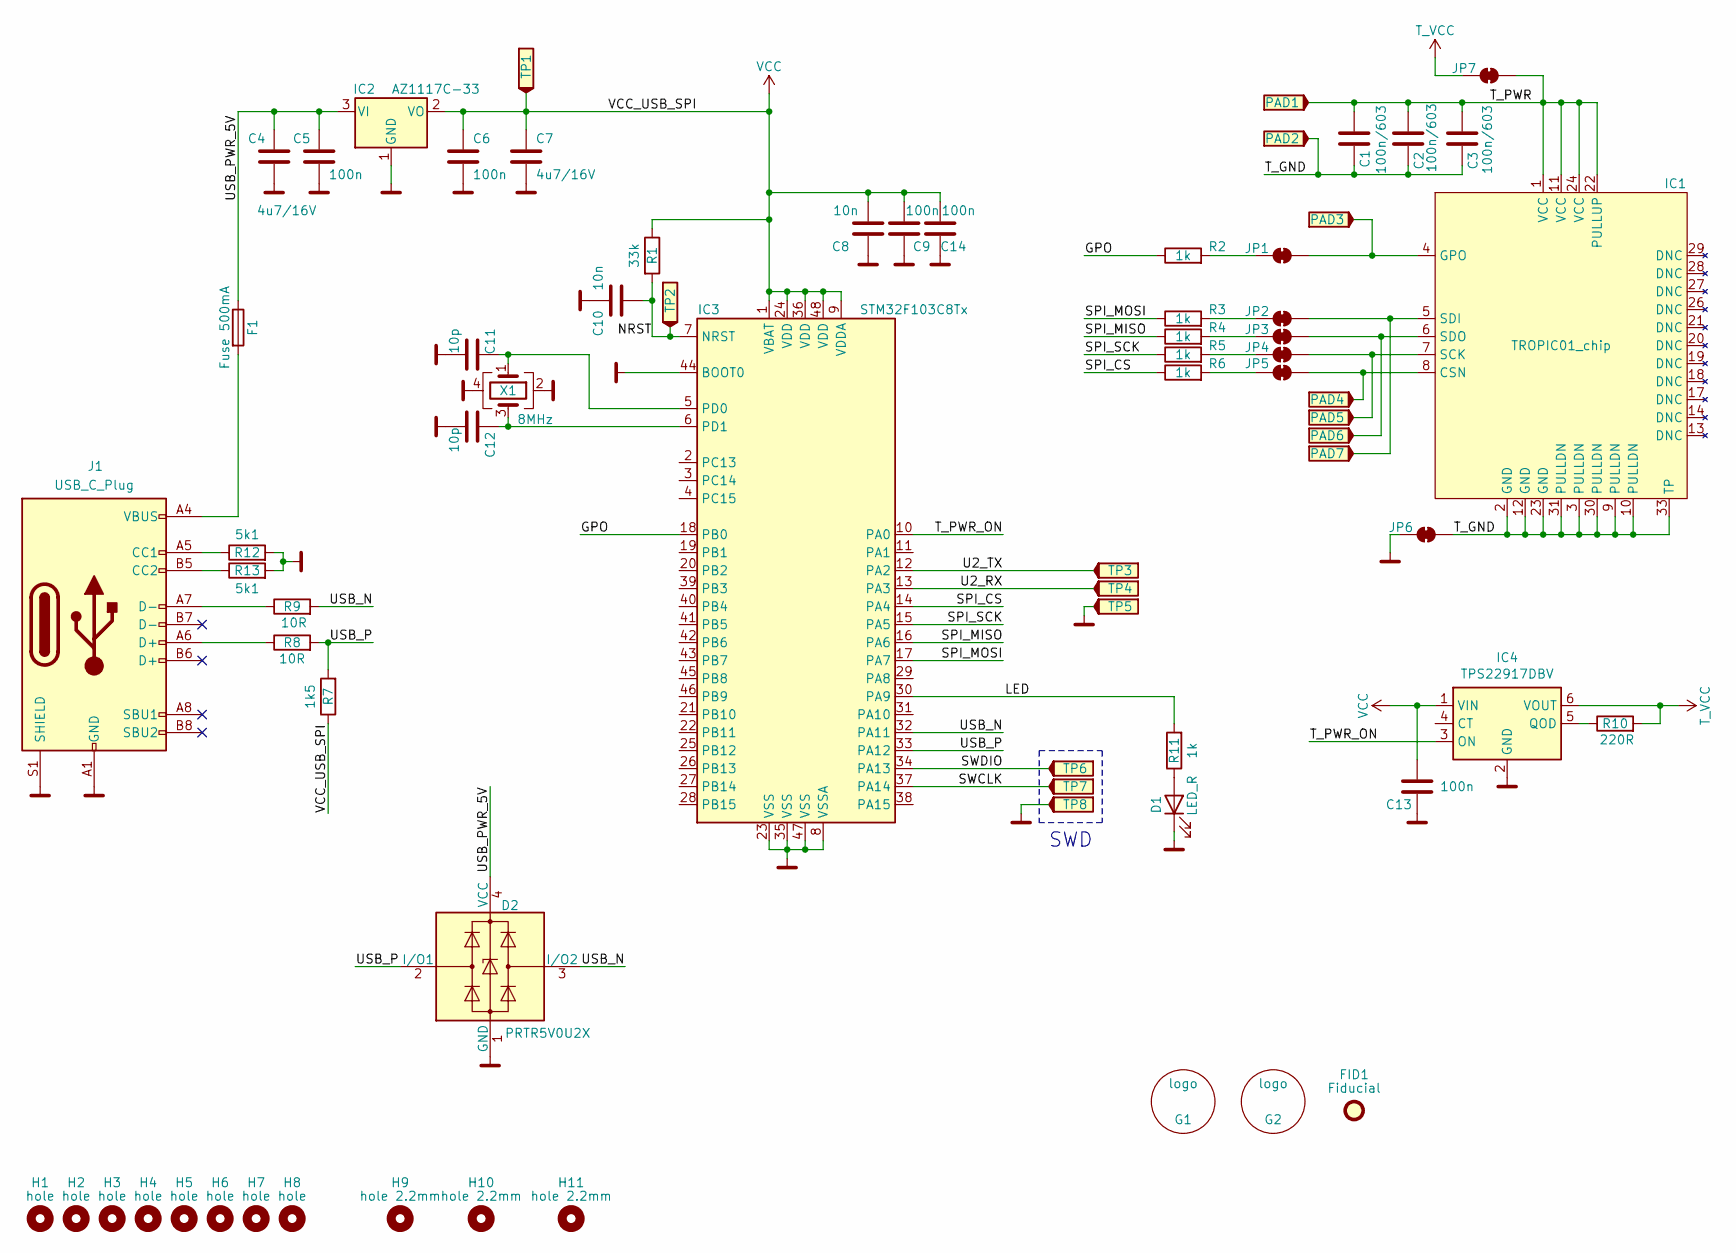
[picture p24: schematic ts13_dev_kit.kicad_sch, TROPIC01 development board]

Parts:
C1, C2, C3: 100n/603; C_0603_1608Metric
C4, C7: 4u7/16V; C_0805_2012Metric
C5, C6, C9, C13, C14: 100n; C_0805_2012Metric
C8, C10: 10n; C_0805_2012Metric
C11, C12: 10p; C_0805_2012Metric
D1: LED_R; LED_0805_2012Metric
D2: PRTR5V0U2X; SOT-143
F1: Fuse 500mA; R_0805_2012Metric_Pad1.20x1.40mm_HandSolder
FID1: Fiducial; Fiducial_0.5mm_Mask1mm
G1: logo; tropicsquare_palm_10
G2: logo; tropicsquare_logo_7
H1, H2, H3, H4, H5, H6, H7, H8: hole; Hole_1.45mm
H9, H10, H11: hole 2.2mm; Hole_2.2mm
IC1: TROPIC01_chip; QFN-32-1EP_4x4mm_P0.4mm_EP2.65x2.65mm
IC2: AZ1117C-33; SOT-223
IC3: STM32F103C8Tx; LQFP-48_7x7mm_P0.5mm
IC4: TPS22917DBV; SOT-23-6; LCSC C2681320
J1: USB_C_Plug; USB_C_plug_USB4155_03_C
JP1, JP2, JP3, JP4, JP5, JP6, JP7: SolderJumper_2_Bridged; SolderJumper-2_P1.3mm_Bridged
PAD1, PAD2, PAD3, PAD4, PAD5, PAD6, PAD7: TP; pad_1mm
R1: 33k; R_0805_2012Metric
R2, R3, R4, R5, R6, R11: 1k; R_0805_2012Metric
R7: 1k5; R_0805_2012Metric
R8, R9: 10R; R_0805_2012Metric
R10: 220R; R_0805_2012Metric
R12, R13: 5k1; R_0805_2012Metric
TP1, TP2, TP3, TP4, TP5, TP6, TP7, TP8: TP; TestPoint_1.5mm_noth
X1: 8MHz; Crystal_SMD_0603-4Pin_6.0x3.5mm

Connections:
/GPO: IC3.18 (PB0), R2.1
/LED: IC3.30 (PA9), R11.2
/NRST: C10.1, IC3.7 (NRST), R1.2, TP2.1
/SPI_CS: IC3.14 (PA4), R6.1
/SPI_MISO: IC3.16 (PA6), R4.1
/SPI_MOSI: IC3.17 (PA7), R3.1
/SPI_SCK: IC3.15 (PA5), R5.1
/SWCLK: IC3.37 (PA14), TP7.1
/SWDIO: IC3.34 (PA13), TP6.1
/T_GND: C1.1, C2.1, C3.1, IC1.2 (GND), IC1.3 (PULLDN), IC1.9 (PULLDN), IC1.10 (PULLDN), IC1.12 (GND), IC1.23 (GND), IC1.30 (PULLDN), IC1.31 (PULLDN), IC1.33 (TP), JP6.2 (B), PAD2.1
/T_PWR: C1.2, C2.2, C3.2, IC1.1 (VCC), IC1.11 (VCC), IC1.22 (PULLUP), IC1.24 (VCC), JP7.2 (B), PAD1.1
/T_PWR_ON: IC3.10 (PA0), IC4.3 (ON)
/U2_RX: IC3.13 (PA3), TP4.1
/U2_TX: IC3.12 (PA2), TP3.1
/USB_N: D2.3 (I/O2), IC3.32 (PA11), R9.2
/USB_P: D2.2 (I/O1), IC3.33 (PA12), R7.2, R8.2
/USB_PWR_5V: C4.1, C5.1, D2.4 (VCC), F1.1, IC2.3 (VI)
GND: C4.2, C5.2, C6.2, C7.2, C8.1, C9.1, C10.2, C11.2, C12.2, C13.1, C14.1, D1.1 (K), D2.1 (GND), IC2.1 (GND), IC3.8 (VSSA), IC3.23 (VSS), IC3.35 (VSS), IC3.44 (BOOT0), IC3.47 (VSS), IC4.2 (GND), J1.A1 (GND), J1.A12 (GND), J1.B1 (GND), J1.B12 (GND), J1.S1 (SHIELD), JP6.1 (A), R12.2, R13.2, TP5.1, TP8.1, X1.2, X1.4
unnamed: D1.2 (A), R11.1
unnamed: F1.2, J1.A4 (VBUS), J1.A9 (VBUS), J1.B4 (VBUS), J1.B9 (VBUS)
unnamed: IC1.8 (CSN), JP5.2 (B), PAD4.1
unnamed: IC1.4 (GPO), JP1.2 (B), PAD3.1
unnamed: IC1.7 (SCK), JP4.2 (B), PAD5.1
unnamed: IC1.5 (SDI), JP2.2 (B), PAD7.1
unnamed: IC1.6 (SDO), JP3.2 (B), PAD6.1
unnamed: C11.1, IC3.5 (PD0), X1.1
unnamed: C12.1, IC3.6 (PD1), X1.3
unnamed: IC4.5 (QOD), R10.1
unnamed: J1.A5 (CC1), R12.1
unnamed: J1.B5 (CC2), R13.1
unnamed: J1.A6 (D+), R8.1
unnamed: J1.A7 (D-), R9.1
unnamed: JP1.1 (A), R2.2
unnamed: JP2.1 (A), R3.2
unnamed: JP3.1 (A), R4.2
unnamed: JP4.1 (A), R5.2
unnamed: JP5.1 (A), R6.2
T_VCC: IC4.6 (VOUT), JP7.1 (A), R10.2
VCC: C6.1, C7.1, C8.2, C9.2, C13.2, C14.2, IC2.2 (VO), IC3.1 (VBAT), IC3.9 (VDDA), IC3.24 (VDD), IC3.36 (VDD), IC3.48 (VDD), IC4.1 (VIN), R1.1, R7.1, TP1.1

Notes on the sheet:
SWD

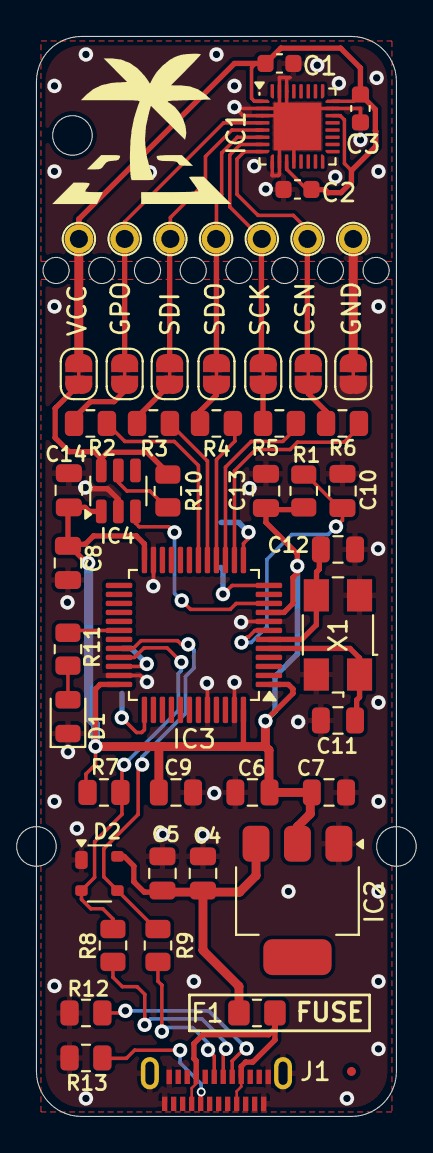
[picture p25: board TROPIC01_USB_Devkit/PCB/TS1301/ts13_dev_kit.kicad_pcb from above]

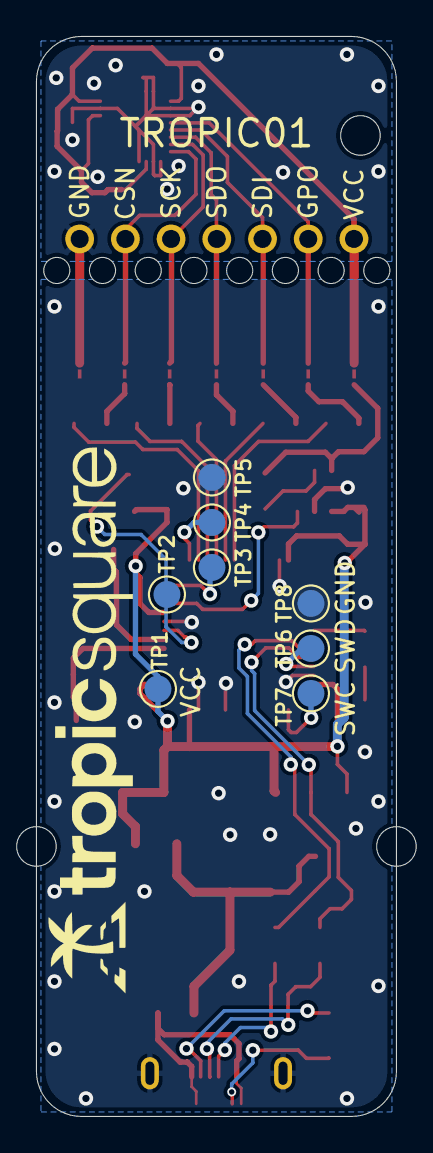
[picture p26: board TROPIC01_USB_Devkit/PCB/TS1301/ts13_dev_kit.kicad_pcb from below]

Board: 2 copper layers, 20.0 x 60.0 mm, 72 parts (9 on the bottom side), 39 nets.

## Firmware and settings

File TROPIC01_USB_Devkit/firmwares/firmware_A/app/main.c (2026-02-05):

#include "os.h"
#include "main.h"
#include "gpio.h"
#include "time.h"
#include "reset.h"
#include "tty.h"
#include "wd.h"
#include "gpreg.h"
#include "led.h"
#include "sys.h"
#include "usb_device.h"
#include "spi.h"
#include "cmd.h"

bool main_spi_auto = false;
u8 main_spi_get_resp = 0;
u8 main_spi_no_resp = 0;

static bool _spi_cs_active = false;
#define _SPI_BUF_SIZE (512)

#define MAIN_LED_INIT  HW_LED1_INIT
#define MAIN_LED_ON    HW_LED1_ON
#define MAIN_LED_OFF   HW_LED1_OFF

static led_t led1;

#define _LED_MODE_IDLE  0x01,4,0
#define _LED_MODE_READY 0x0F,4,0

static u8 reset_type = RESET_POWER_ON;

static void main_gpio_init(void)
{
    gpio_init();

    MAIN_LED_INIT;
    MAIN_LED_ON;

    HW_SPI_OE_DISABLE;
    HW_SPI_OE_INIT;

    HW_GPO0_IN_INIT;
    HW_GPO1_IN_INIT;
    HW_GPO2_IN_INIT;
    HW_GPO3_IN_INIT;
    HW_GPO4_IN_INIT;

    HW_MODE0_IN_INIT;
    HW_MODE1_IN_INIT;
    HW_MODE2_IN_INIT;
    HW_MODE3_IN_INIT;

    HW_VCC_RESET_INIT;
    HW_VCC_RESET_CLR;
}

void Error_Handler(void)
{
    // User can add his own implementation to report the HAL error return state
    __disable_irq();
    while (1)
    {
        MAIN_LED_ON;
        OS_DELAY(100);
        MAIN_LED_OFF;
        OS_DELAY(100);
    }
}

static bool _get_hex(u8 *dest, const char *src)
{   // read one byte of HEX value
    if (hex_to_bin(dest, src, 1) != 1)
        return (false);

    return (true);
}

static void _led1_on (void)
{
    MAIN_LED_ON;
}

static void _led1_off (void)
{
    MAIN_LED_OFF;
}

static void _spi_cs_enable(void)
{
    spi1_cs(true);
    _spi_cs_active = true;
}

static void _spi_cs_disable(void)
{
    spi1_cs(false);
    _spi_cs_active = false;
}

static void _spi_auto_task(void)
{   //
    char spi_buf[_SPI_BUF_SIZE];
    int i, l;

    spi1_flush();

    _spi_cs_enable();

    spi_buf[0] = spi1_transfer(main_spi_get_resp);
    // TODO: we can check busy bit here
    spi_buf[0] = spi1_transfer(0); // header

    if (spi_buf[0] == main_spi_no_resp)
    {   // no response to read
        _spi_cs_disable();
        // TODO: automatic read MSG_HDR_DEBUG ?
        return;
    }

    l = spi1_transfer(0);
    spi_buf[1] = l; // data length

    for (i=2; i<(2+l+2); i++)
    {
        spi_buf[i] = spi1_transfer(0);
    }
    
    _spi_cs_disable();

    // print result
    for (i=0; i<(2+l+2); i++)
    {
        OS_PRINTF("%02X", spi_buf[i]);
    }
    OS_PRINTF(NL);
}

static bool _skip_cs_char(char ch)
{   // following characters can be used for skip CS manipulation
    // only usable as first or last character (or both) in SPI data stream
    return (((ch == 'x') || (ch == '\\')) ? true : false);
}

static bool _parse_hex(char *data)
{
    char spi_tx_buf[_SPI_BUF_SIZE];
    char spi_rx_buf[_SPI_BUF_SIZE];
    int buf_size = 0;
    int i;
    u8 tmp;
    bool skip_cs = false;

    if (_skip_cs_char(*data))
    {   // 
        data++;
        skip_cs = true;
    }

    if (! _get_hex(&tmp, data))
        return (false);

    // convert HEX to binary data to buffer
    do
    {
        data+=2;
        while (*data == ' ')
            data++; // skip spaces

        spi_tx_buf[buf_size] = tmp;

        if (buf_size < (_SPI_BUF_SIZE-1))
            buf_size++;
    }
    while (_get_hex(&tmp, data));

    _led1_off();

    if (skip_cs == false)
    {
        _spi_cs_enable();
    }

    // transfer buffer to spi
    spi1_data_transfer(spi_rx_buf, spi_tx_buf, buf_size);

    if (! _skip_cs_char(*data))
        _spi_cs_disable();

    // print result
    for (i=0; i<buf_size; i++)
    {
        OS_PRINTF("%02X", spi_rx_buf[i]);
    }
    OS_PRINTF(NL);
    return (true);
}

static void _tty_rx_parser(char *data)
{
    while (*data == ' ')
        data++; // skip spaces

    if (! _parse_hex(data))
    {
        cmd_parse(data);
    }
    OS_FLUSH();
}

static void _usb_update_state(void)
{
    static bool prev_state = false;
    
    bool state = usb_device_connected();

    if (prev_state == state)
        return;

    if (state)
    {
        // OS_PUTTEXT("READY" NL);
        led_cyclic_sequence(&led1, _LED_MODE_READY);
        HW_SPI_OE_ENABLE;
    }
    else
    {
        led_cyclic_sequence(&led1, _LED_MODE_IDLE);
        HW_SPI_OE_DISABLE;
    }

    prev_state = state;
}

static void _main_task(void)
{
    os_timer_t now, timer_100ms = 0;
    os_timer_t timer_10s = 0;

    reset_clear();
    
    led_init(&led1);
    led1.on = _led1_on;
    led1.off = _led1_off;
    led_cyclic_sequence(&led1, _LED_MODE_IDLE);
    
    usb_device_init();
    spi1_init();

    timer_100ms = timer_get_time();
    timer_10s = timer_100ms;

    while (1)
    {
        now = timer_get_time();
        tty_rx_task();

        if (now > timer_100ms)
        {
            _usb_update_state();
            timer_100ms += 100*TIMER_MS;
            led_tick(&led1);
            wd_feed();
            if (main_spi_auto)
            {
                if (_spi_cs_active == false)
                {
                    _spi_auto_task();
                }
            }
        }
        if (now > timer_10s)
        {
            timer_10s += 10*1000*TIMER_MS;
            // 
        }
        __WFI(); // at least 1ms timer IRQ running
    }
}

int main(void)
{
    sys_init();
    
    sys_clock_config();
    main_gpio_init();
    
    wd_init();
    wd_run();

    reset_type = reset_get_type();

    timer_init();

    OS_DELAY(10);
    tty_init(_tty_rx_parser);
    OS_DELAY(10);

    OS_PUTTEXT(NL);
    OS_PUTTEXT("APP START" NL);
    MAIN_LED_OFF;

    OS_PUTTEXT("# BUILD DATE: " __DATE__ NL);

    OS_PUTTEXT("# RESET TYPE: ");
    switch (reset_type)
    {
    case RESET_POWER_ON: OS_PUTTEXT("POWER_ON"); break;
    case RESET_USER_RQ:  OS_PUTTEXT("USER_RQ");  break;
    case RESET_WDT:      OS_PUTTEXT("WDT");      break;
    case RESET_BOD:      OS_PUTTEXT("BOD");      break;
    default:             OS_PUTTEXT("UNKNOWN");  break;
    }
    OS_PUTTEXT(NL);
    OS_PUTTEXT(NL);

    _main_task();

    // should never continue here
    while (1)
        ;
}

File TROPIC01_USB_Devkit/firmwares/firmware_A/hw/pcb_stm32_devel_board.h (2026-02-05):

#ifndef PCB_H
#define PCB_H

#define	HW_HSE_ENABLED 1 // HSE crystal 8MHz assembled 

// LED connected to VCC (not GND)
#define HW_LED1_BIT   (13)
#define HW_LED1_PORT  GPIOC
#define HW_LED1_INIT  GPIO_PIN_INIT(HW_LED1_PORT, HW_LED1_BIT, GPIO_MODE_OUTPUT)
#define HW_LED1_ON    {GPIO_BIT_CLR(HW_LED1_PORT, HW_LED1_BIT); GPIO_MODE(HW_LED1_PORT, HW_LED1_BIT, GPIO_MODE_OUTPUT);}
#define HW_LED1_OFF   GPIO_MODE(HW_LED1_PORT, HW_LED1_BIT, GPIO_MODE_FLOATING) 

#define HW_LED2_ON
#define HW_LED2_OFF

// uart2 == ui
#define HW_UART2_ON 1
#define	HW_UART2_RX_BIT  3
#define	HW_UART2_RX_PORT GPIOA
#define	HW_UART2_TX_BIT  2
#define	HW_UART2_TX_PORT GPIOA
#define	HW_UART2_GPIO_EN RCC_APB2ENR_IOPAEN

#define HW_CONSOLE_ON_UART
#define	HW_TTY_UART_GETCHAR() uart2_getchar()
#define	HW_TTY_UART_PUTCHAR(ch) uart2_putchar(ch)
#define	HW_TTY_UART_INIT(baud) uart2_init(baud)

// HW SPI support
#define SPI1_ON  1

#define HW_SPI_SW_CS_BIT    (4)
#define HW_SPI_SW_CS_PORT   GPIOA
#define HW_SPI_SW_CS_INIT   GPIO_PIN_INIT(HW_SPI_SW_CS_PORT, HW_SPI_SW_CS_BIT, GPIO_MODE_OUTPUT)
#define HW_SPI_SW_CS_UP     GPIO_BIT_SET(HW_SPI_SW_CS_PORT,HW_SPI_SW_CS_BIT)
#define HW_SPI_SW_CS_DOWN   GPIO_BIT_CLR(HW_SPI_SW_CS_PORT,HW_SPI_SW_CS_BIT)

/*
// SW SPI support

#define HW_SPI_SW_SCK_BIT   (5)
#define HW_SPI_SW_SCK_PORT  GPIOA
#define HW_SPI_SW_SCK_INIT  GPIO_PIN_INIT(HW_SPI_SW_SCK_PORT,HW_SPI_SW_SCK_BIT,GPIO_MODE_OUTPUT)
#define HW_SPI_SW_SCK_UP    GPIO_BIT_SET(HW_SPI_SW_SCK_PORT,HW_SPI_SW_SCK_BIT)
#define HW_SPI_SW_SCK_DOWN  GPIO_BIT_CLR(HW_SPI_SW_SCK_PORT,HW_SPI_SW_SCK_BIT)

#define HW_SPI_SW_MISO_BIT  (6)
#define HW_SPI_SW_MISO_PORT GPIOA
#define HW_SPI_SW_MISO_INIT GPIO_PIN_INIT(HW_SPI_SW_MISO_PORT, HW_SPI_SW_MISO_BIT,GPIO_MODE_INPUT)
#define HW_SPI_SW_MISO_IN   GPIO_IN(HW_SPI_SW_MISO_PORT, HW_SPI_SW_MISO_BIT)

#define HW_SPI_SW_MOSI_BIT  (7)
#define HW_SPI_SW_MOSI_PORT GPIOA
#define HW_SPI_SW_MOSI_INIT GPIO_PIN_INIT(HW_SPI_SW_MOSI_PORT, HW_SPI_SW_MOSI_BIT, GPIO_MODE_OUTPUT)
#define HW_SPI_SW_MOSI_UP   GPIO_BIT_SET(HW_SPI_SW_MOSI_PORT,HW_SPI_SW_MOSI_BIT)
#define HW_SPI_SW_MOSI_DOWN GPIO_BIT_CLR(HW_SPI_SW_MOSI_PORT,HW_SPI_SW_MOSI_BIT)
*/

// output enable (level shifter enable)
#define HW_SPI_OE_BIT       (8)
#define HW_SPI_OE_PORT      GPIOA
#define HW_SPI_OE_INIT      GPIO_PIN_INIT(HW_SPI_OE_PORT,HW_SPI_OE_BIT,GPIO_MODE_OUTPUT)
#define HW_SPI_OE_ENABLE    GPIO_BIT_SET(HW_SPI_OE_PORT,HW_SPI_OE_BIT)
#define HW_SPI_OE_DISABLE   GPIO_BIT_CLR(HW_SPI_OE_PORT,HW_SPI_OE_BIT)

// Target GPO reading
#define HW_GPO0_IN_BIT      (0)
#define HW_GPO0_IN_PORT     GPIOB
#define HW_GPO0_IN_INIT     GPIO_PIN_INIT(HW_GPO0_IN_PORT,HW_GPO0_IN_BIT,GPIO_MODE_INPUT)
#define HW_GPO0_IN          GPIO_IN(HW_GPO0_IN_PORT,HW_GPO0_IN_BIT)

#define HW_GPO1_IN_BIT      (1)
#define HW_GPO1_IN_PORT     GPIOB
#define HW_GPO1_IN_INIT     GPIO_PIN_INIT(HW_GPO1_IN_PORT,HW_GPO1_IN_BIT,GPIO_MODE_INPUT)
#define HW_GPO1_IN          GPIO_IN(HW_GPO1_IN_PORT,HW_GPO1_IN_BIT)

#define HW_GPO2_IN_BIT      (2)
#define HW_GPO2_IN_PORT     GPIOB
#define HW_GPO2_IN_INIT     GPIO_PIN_INIT(HW_GPO2_IN_PORT,HW_GPO2_IN_BIT,GPIO_MODE_INPUT)
#define HW_GPO2_IN          GPIO_IN(HW_GPO2_IN_PORT,HW_GPO2_IN_BIT)

#define HW_GPO3_IN_BIT      (3)
#define HW_GPO3_IN_PORT     GPIOB
#define HW_GPO3_IN_INIT     GPIO_PIN_INIT(HW_GPO3_IN_PORT,HW_GPO3_IN_BIT,GPIO_MODE_INPUT)
#define HW_GPO3_IN          GPIO_IN(HW_GPO3_IN_PORT,HW_GPO3_IN_BIT)

#define HW_GPO4_IN_BIT      (4)
#define HW_GPO4_IN_PORT     GPIOB
#define HW_GPO4_IN_INIT     GPIO_PIN_INIT(HW_GPO4_IN_PORT,HW_GPO4_IN_BIT,GPIO_MODE_INPUT)
#define HW_GPO4_IN          GPIO_IN(HW_GPO4_IN_PORT,HW_GPO4_IN_BIT)

// Target MODE reading
// TEST_MODE
#define HW_MODE0_IN_BIT      (8)
#define HW_MODE0_IN_PORT     GPIOB
#define HW_MODE0_IN_INIT     {GPIO_PIN_INIT(HW_MODE0_IN_PORT,HW_MODE0_IN_BIT,GPIO_MODE_INPUT); GPIO_PUPDN(HW_MODE0_IN_PORT,HW_MODE0_IN_BIT, GPIO_PUPDN_DN);}
#define HW_MODE0_IN          GPIO_IN(HW_MODE0_IN_PORT,HW_MODE0_IN_BIT)

// SCAN_MODE
#define HW_MODE1_IN_BIT      (9)
#define HW_MODE1_IN_PORT     GPIOB
#define HW_MODE1_IN_INIT     GPIO_PIN_INIT(HW_MODE1_IN_PORT,HW_MODE1_IN_BIT,GPIO_MODE_INPUT)
#define HW_MODE1_IN          GPIO_IN(HW_MODE1_IN_PORT,HW_MODE1_IN_BIT)

// FTEST_MODE
#define HW_MODE2_IN_BIT      (10)
#define HW_MODE2_IN_PORT     GPIOB
#define HW_MODE2_IN_INIT     GPIO_PIN_INIT(HW_MODE2_IN_PORT,HW_MODE2_IN_BIT,GPIO_MODE_INPUT)
#define HW_MODE2_IN          GPIO_IN(HW_MODE2_IN_PORT,HW_MODE2_IN_BIT)

// SEL_EXT_CLK
#define HW_MODE3_IN_BIT      (11)
#define HW_MODE3_IN_PORT     GPIOB
#define HW_MODE3_IN_INIT     GPIO_PIN_INIT(HW_MODE3_IN_PORT,HW_MODE3_IN_BIT,GPIO_MODE_INPUT)
#define HW_MODE3_IN          GPIO_IN(HW_MODE3_IN_PORT,HW_MODE3_IN_BIT)
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

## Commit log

2026-01-15 Initial commit collecting all pcb resources for TROPIC01 devboards to create single repository
    [bom.csv, bom_variant_chip.csv, bom_variant_microbus.csv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]
2026-01-16 feat: Update legacy firmware A files
    [bom.csv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]
2026-01-20 feat: Add KiCAD library files
    [TROPIC01.step]
2026-01-21 feat: Update KiCAD library, update readme
2026-01-21 ref: Rename KiCAD to KiCad
    [TROPIC01.step]
2026-01-21 feat: Add TS1303 design files
    [bom.csv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]
2026-01-21 ref: Rename pcb to PCB, update readmes
    [bom.csv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]
2026-01-22 doc: Unify devboard readmes and folder names for all devboards
    [bom_variant_chip.csv, bom_variant_microbus.csv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]
2026-01-22 fix: Update name for kicad banner
2026-01-22 doc: Update KiCad readme
2026-01-23 ref: Add TROPIC01 to all devboards' names
    [bom.csv, bom_variant_chip.csv, bom_variant_microbus.csv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]
2026-01-29 feat: update PCB marking and TR01 PN allocation to each devkit
2026-02-05 feat: add MIKRO-E click board variants
2026-02-25 feat: Add Silkscreen rectangle to TS1501
    [ts15-rpi-shield.kicad_pcb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]
2026-02-25 feat: Add silkscreen rectangle to TS1303
    [ts13_dev_kit.kicad_pcb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]
2026-02-25 feat: Add silkscreen rectangle to TS1401
    [ts14-arduino-shield.kicad_pcb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]
2026-02-25 feat: Add TS1702 files
    [ts17-tropic01-mini-B_Cu.gbr, ts17-tropic01-mini-B_Mask.gbr, ts17-tropic01-mini-B_Silkscreen.gbr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]
